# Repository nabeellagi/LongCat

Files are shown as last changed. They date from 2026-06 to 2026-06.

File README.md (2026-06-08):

<div align="center">

<!-- Zine -->
<a href="zine/zine.png">
  Long Cat & FoxCharge Zine
</a>

---

# Long Cat & FoxCharge

**A custom ESP32-C6 retro game console + fox-themed powerbank, built from scratch.**  
*By Nabeel — 18, Indonesia*

```
   /\_____/\
  /  o   o  \
 ( ==  ^  == )
```

</div>

---

## What Is This?

Long Cat is a handheld retro game console built around a custom ESP32-C6 PCB, put inside a 3D-printed enclosure featuring a long, stoopid cat on the back. It has a 1.3" OLED screen, 5 interface buttons, and a passive buzzer.

FoxCharge is its companion: a fox-themed powerbank with its own custom PCB, and a "Charging Social Battery" label on the back — totally relateable.

---

## Why Does This Exist?
The whole thing exists because I wanted a device where anyone could write their own retro-style game in firmware and actually play it on real hardware! A customizable silly looking project.

---

## How To Use It

### Coding & Flashing

This is the main loop. Open up Arduino IDE, write your game, and flash it to the console over USB-C.

1. Install [Arduino IDE](https://www.arduino.cc/en/software) and add ESP32 board support
2. Plug the console into your PC via USB-C
3. Open or write your game sketch
4. Select the correct board: **ESP32C6 Dev Module**
5. Hit upload, watch it flash, iterate :D

The enclosure pops open magnetically so you never need to unscrew anything to get to the board.

### Playing & Sharing

Once your game is ready and you want to take it somewhere — or just not be tethered to a laptop:

1. Plug the console into the **FoxCharge powerbank** via USB-C
2. The console powers up from the powerbank's 5V output
3. Hand it to a friend. Or play it yourself.

### Modifying the Hardware

Want to tweak the circuit? Change a pin assignment? Add something new? Here's where to go:

- **Console PCB** — open `PCB/board/board.kicad_pro` in [KiCad](https://www.kicad.org/). The schematic, layout, and production files are all in there.
- **FoxCharge PCB** — open `PCB/powerbank/powerbank.epro` in [EasyEDA](https://easyeda.com/). The Interactive BOM HTML (`PCB/powerbank/INTERACTIVE BOM/InteractiveBOM_PCB1_2026-5-30.html`) is very helpful for cross-referencing components on the board visually.

---

## Hardware Overview

### Console

The brain of Long Cat. Designed in KiCad, built around the ESP32-C6.

| Part | What it does |
|---|---|
| **ESP32-C6** | The microcontroller. RISC-V, Wi-Fi 6, BLE 5. Runs your game code. |
| **1.3" OLED** | The screen. I2C, connected on SDA/SCL. This is where everything gets drawn. |
| **5x Buttons** | `BTN_1` through `BTN_5` — your game inputs. Wired to dedicated GPIO pins. |
| **Passive Buzzer** | Makes noise. Driven by a transistor on `BUZZER_PIN`. Louder than what you'd expect!! |
| **Reset / Boot switches** | `SW1` = reset the board, `SW2` = enter bootloader. Useful during development. |
| **Debug header (J1)** | 6-pin header exposing EN, 3V3, TX, GND, RX, BOOT — for serial monitoring or alternate flashing setups. |

### FoxCharge Powerbank

The power source. Custom PCB designed in EasyEDA. Fox-themed. Sleeping fox on the front is load-bearing.

| Part | What it does |
|---|---|
| **Battery** | LiPo 103450 cell (~2000 mAh). |
| **Charge IC — TP4056** | Handles charging the LiPo safely from the USB-C input port. |
| **Boost IC — MT3608** | Steps up the battery voltage (~3.7V) to a stable 5V for the USB-C output. |
| **Protection IC — DW01A + FS8205A** | Protects the battery from overcharge, overdischarge, and short circuits. Keeps things from catching fire. |
| **USB-C Input** | Plug in a charger here to charge the battery. |
| **USB-C Output** | Plug the console here. This is what powers the game. |

---

## Assembly

### Long Cat Console

<p align="center">
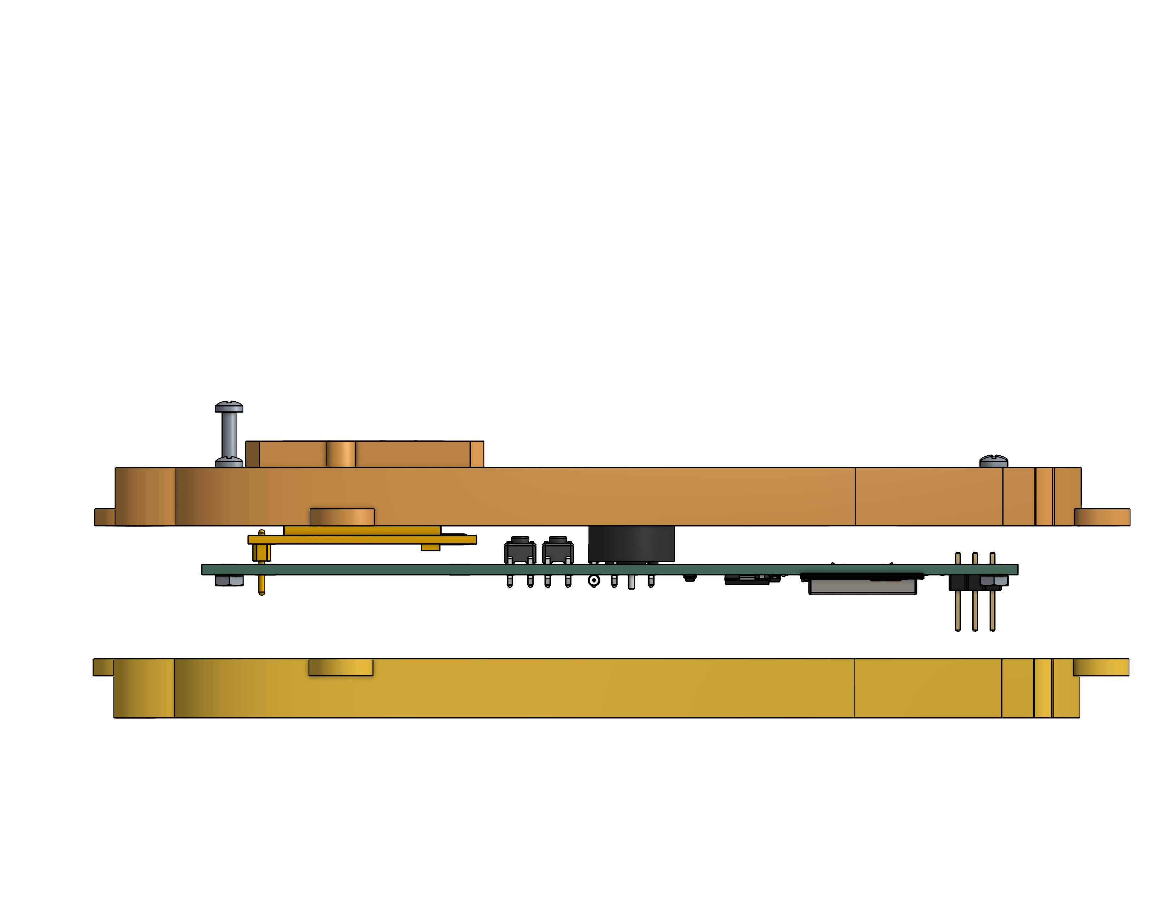
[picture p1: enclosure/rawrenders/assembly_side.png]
Console assembly side view
  
  <br/>
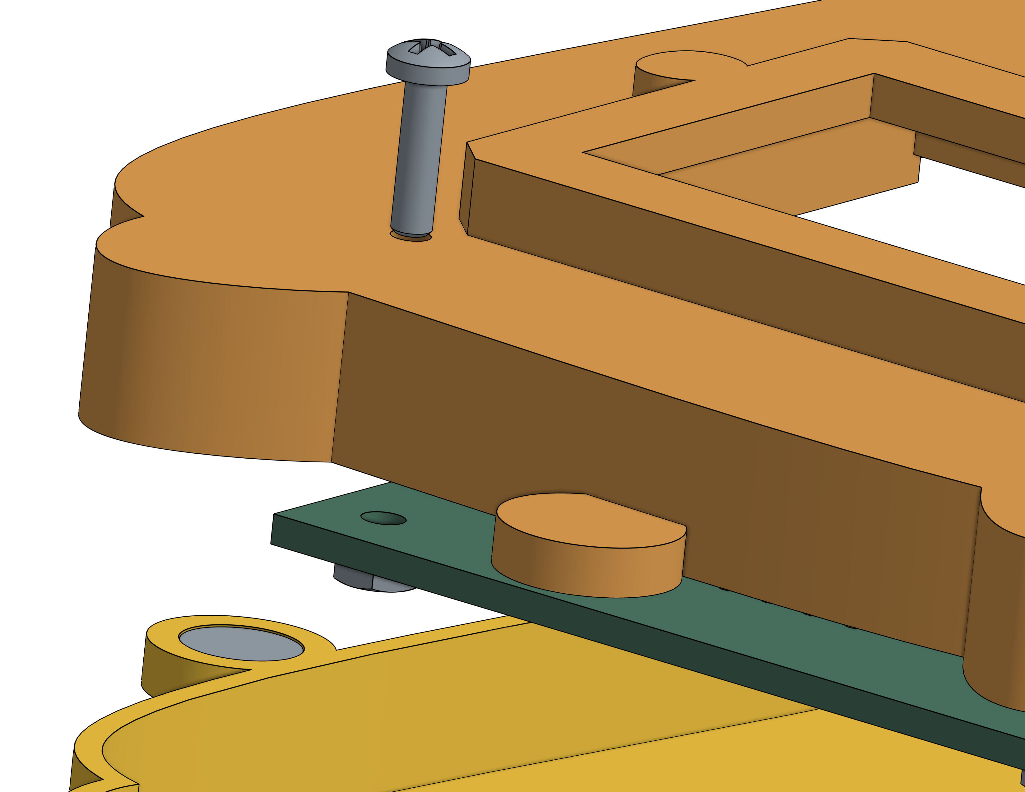
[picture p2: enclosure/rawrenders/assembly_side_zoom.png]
Console assembly side zoom
  
  <br/>
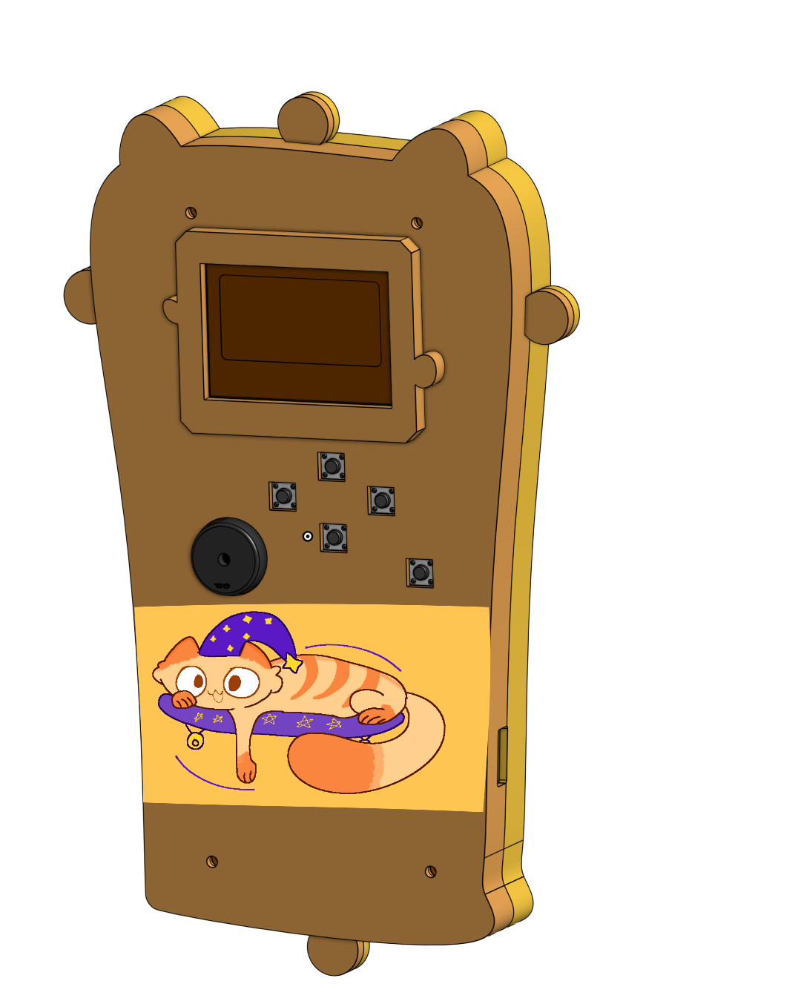
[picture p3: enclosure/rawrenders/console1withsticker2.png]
Console with Long Cat sticker
  
</p>

The front and back halves of the enclosure are held together using **6 x 2mm neodymium magnets** on the edges. This means the case snaps shut cleanly and can be pulled apart for flashing or debugging without any tools — which matters a lot when you're iterating on your game code.

To secure the PCB inside the front half: use **M2 screws with nylon M2 nuts**. Nylon nuts ensures the PCB will be locked into the top of the enclosure. Full screw spec is in the BOM (`REAL_BOM/console.csv`).

The Long Cat sticker goes on the back and the Sleepy cat on the front. **This is not optional!!!**.

---

### FoxCharge Powerbank

<p align="center">
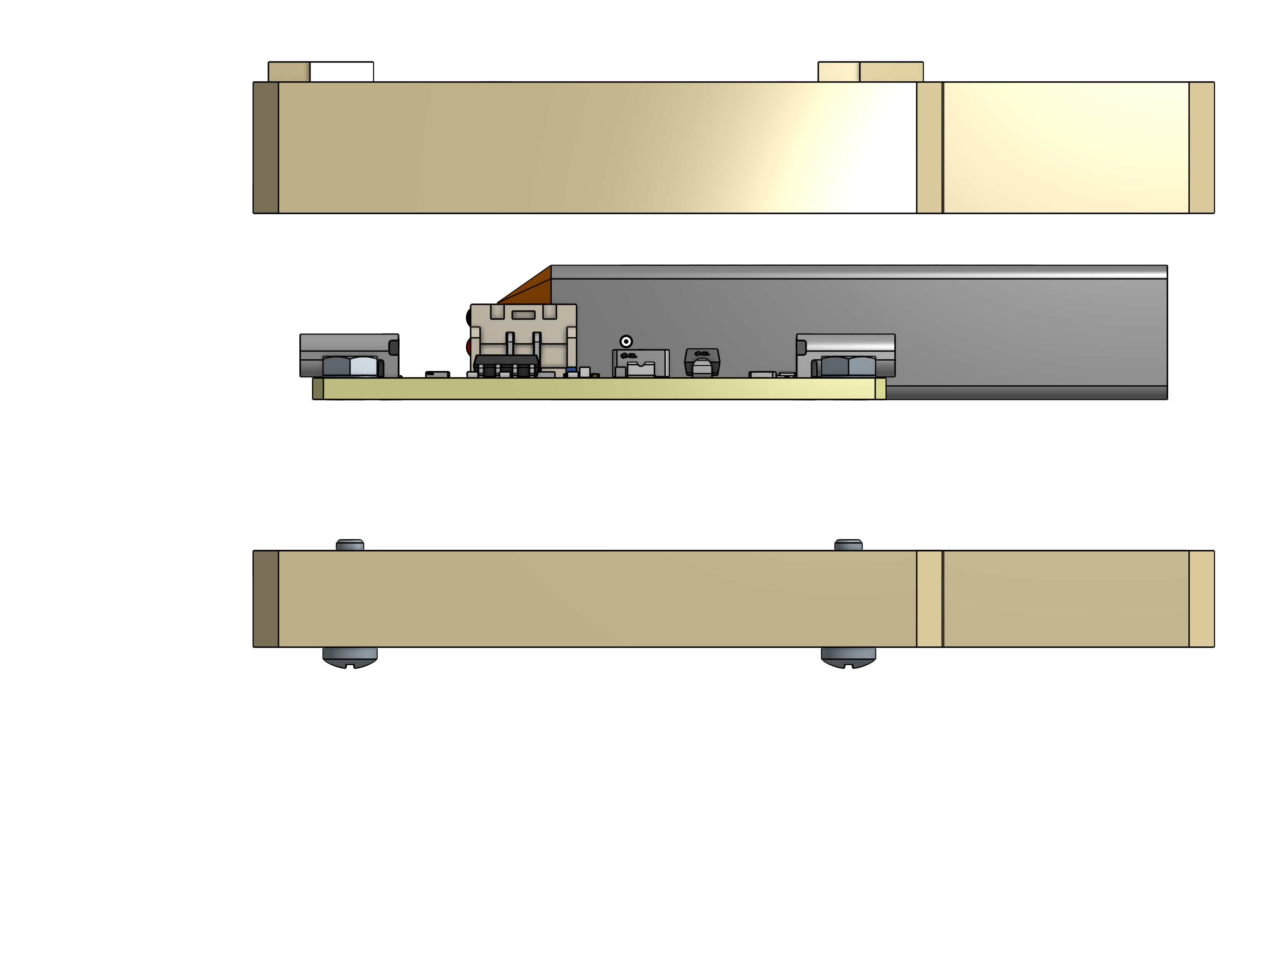
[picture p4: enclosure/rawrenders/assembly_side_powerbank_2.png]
Powerbank assembly view 2
  
  <br/>
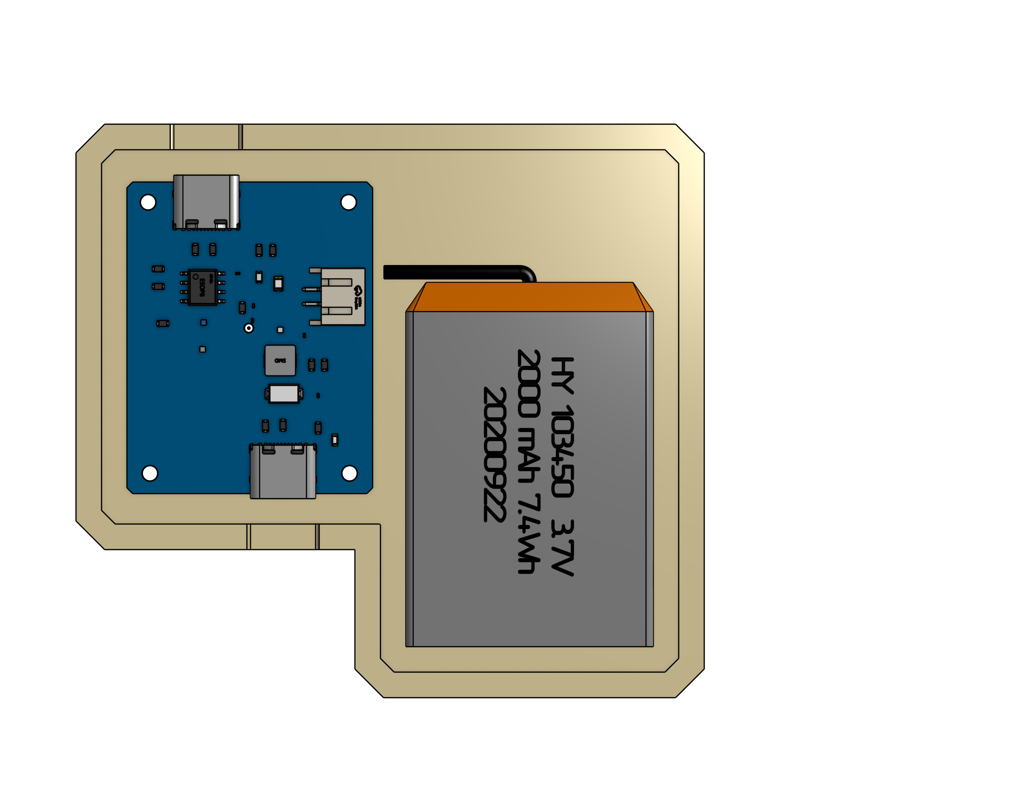
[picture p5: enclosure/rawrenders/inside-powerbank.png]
Powerbank inside view
  
  <br/>
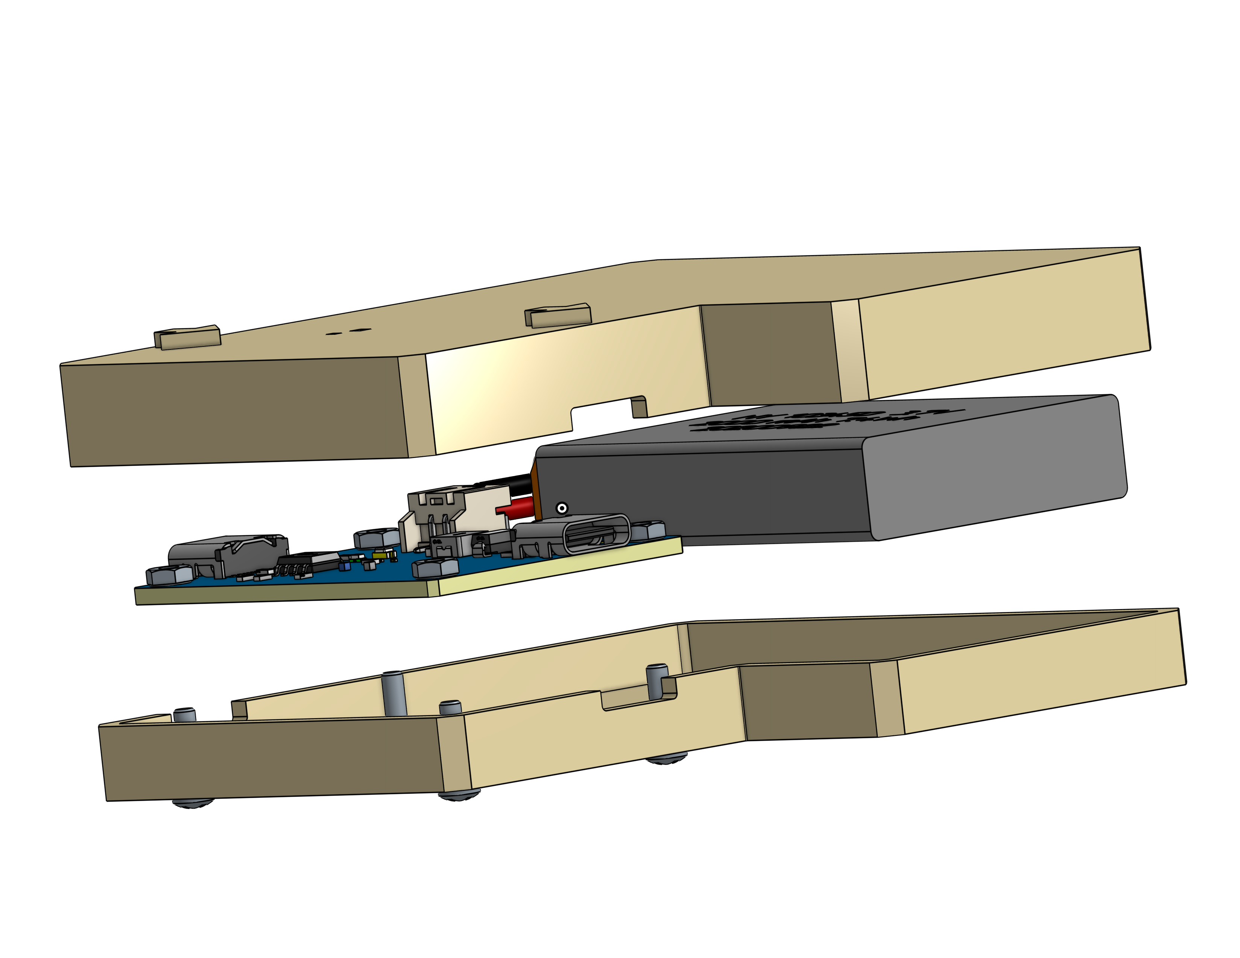
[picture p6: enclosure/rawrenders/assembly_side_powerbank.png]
Powerbank assembly side view
  
  <br/>
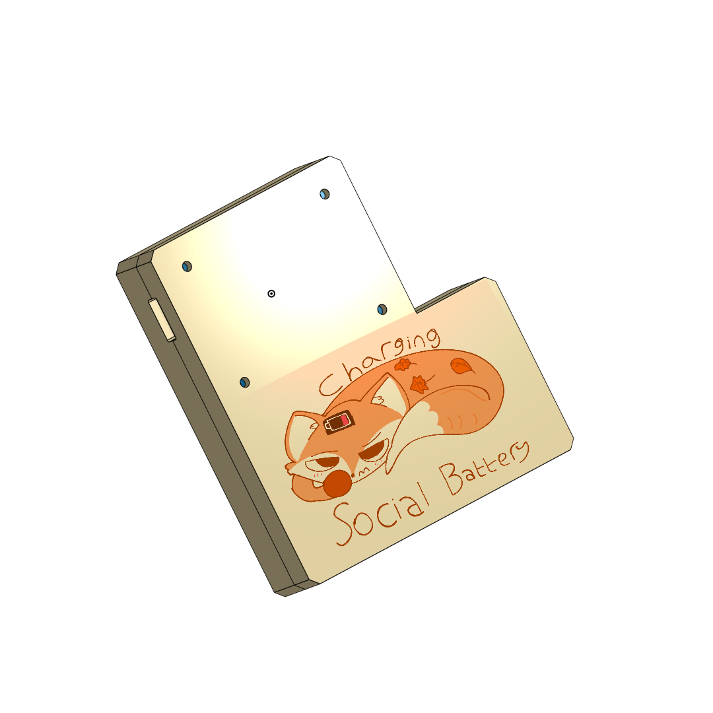
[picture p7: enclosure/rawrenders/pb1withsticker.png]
  
</p>

Inside the powerbank enclosure, the LiPo battery and PCB are separated using **padded EVA foam** to prevent contact, pressure damage, and general battery unhappiness.

On the inner edges, **Dual Lock Reclosable Fastener (24mm × 50cm Velcro-style)** is used to hold the assembly in place while still allowing it to be opened cleanly for battery replacement or inspection.
<p align="center">
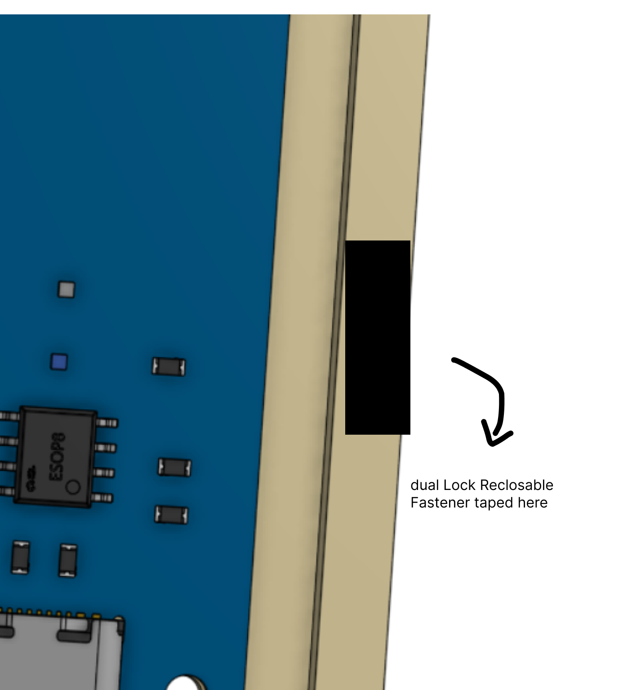
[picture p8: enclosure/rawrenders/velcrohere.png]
  
</p>
Same M2 screw + nylon nut approach as the console for securing the PCB. See `REAL_BOM/powerbank.csv` for the full list.

---

### PCB and Schematics Wiring

<p align="center">
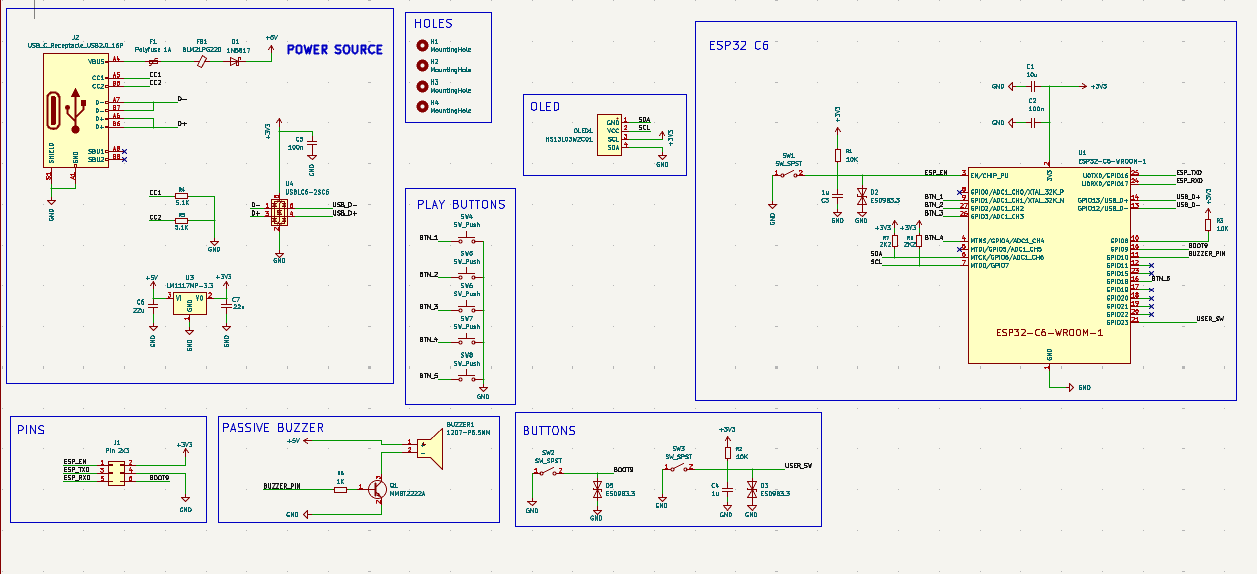
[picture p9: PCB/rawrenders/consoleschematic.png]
Console schematic
  
  <br/>
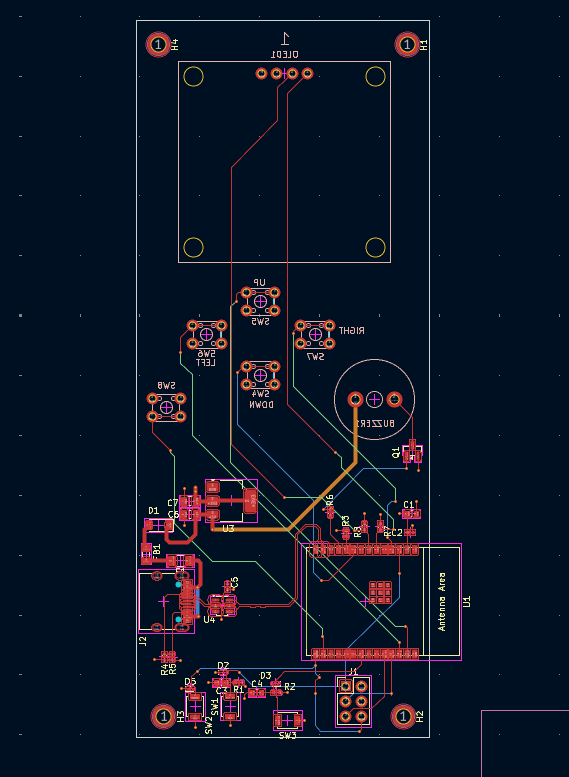
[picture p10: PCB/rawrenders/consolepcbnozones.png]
Console PCB without zones
  
  <br/>
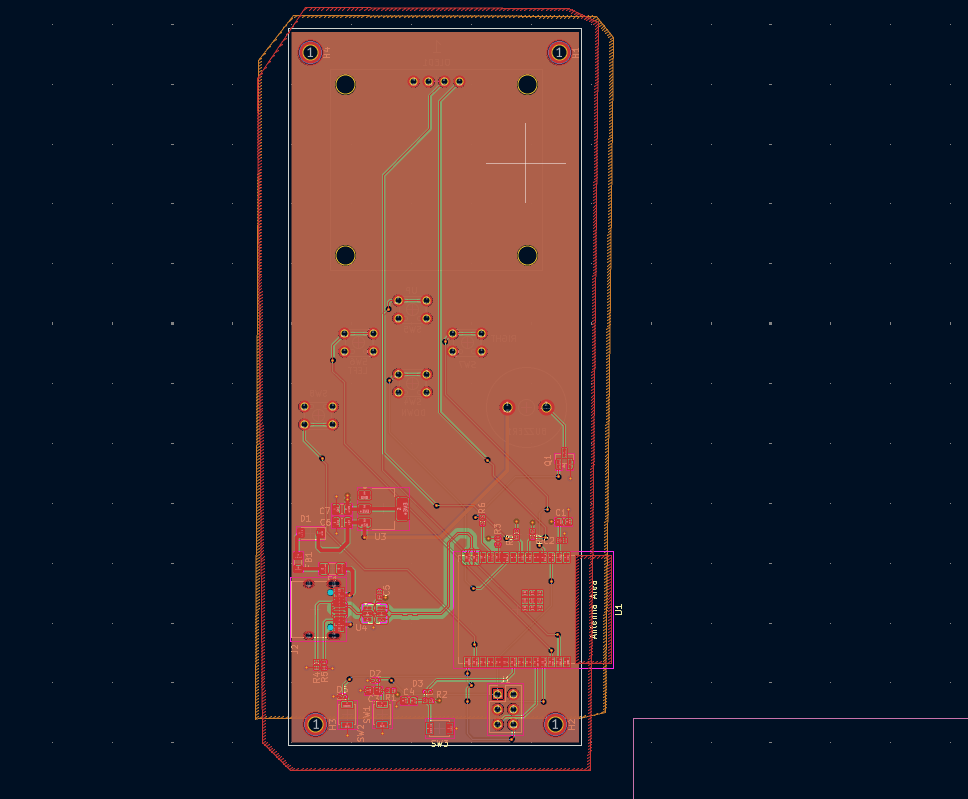
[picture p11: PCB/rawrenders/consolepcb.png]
Console PCB
  
  <br/>
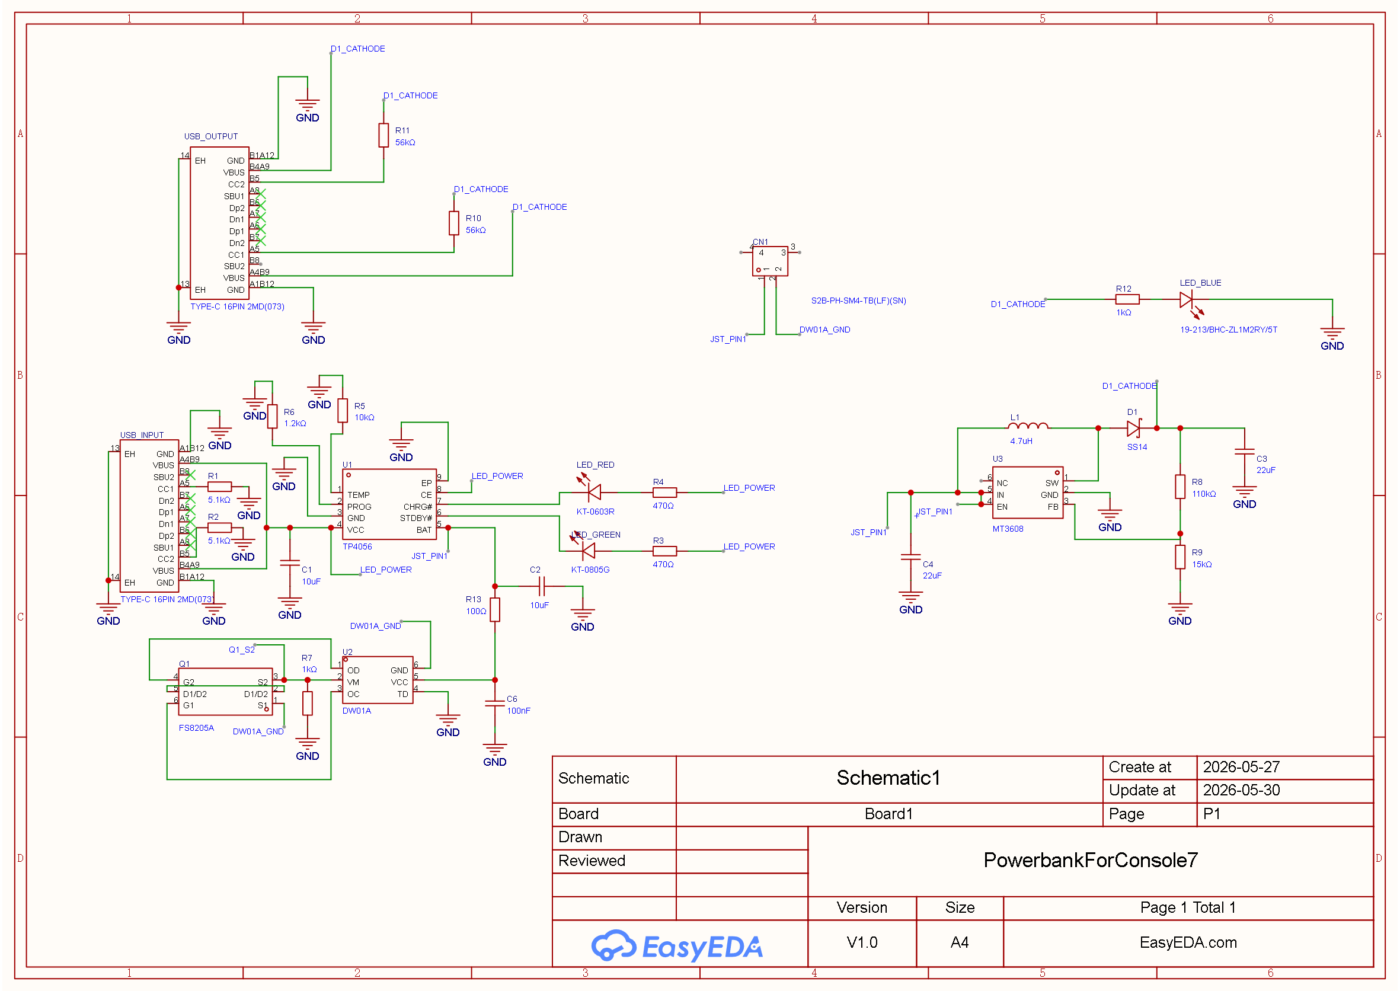
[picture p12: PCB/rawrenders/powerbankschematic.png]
Powerbank schematic
  
  <br/>
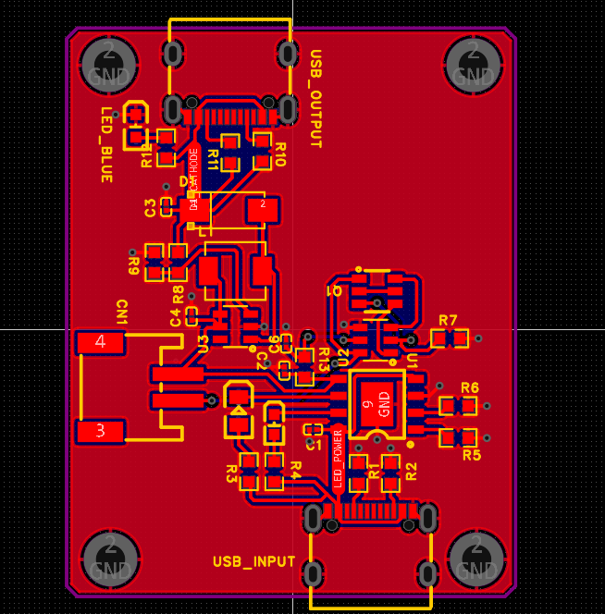
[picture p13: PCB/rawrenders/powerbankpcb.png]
Powerbank PCB
  

</p>

---

## Repository Structure

```
.
├── PCB/
│   ├── board/                          # Console PCB (KiCad)
│   │   ├── board.kicad_pcb
│   │   ├── board.kicad_sch
│   │   ├── board.kicad_pro
│   │   ├── STEP/board.step
│   │   └── production/
│   │       ├── board_gerber.zip        # Send this to your fab
│   │       ├── netlist.ipc
│   │       ├── bom.csv-JLCPCB BOM Tool.xls
│   │       └── raw_bom.csv
│   └── powerbank/                      # FoxCharge PCB (EasyEDA)
│       ├── powerbank.epro
│       ├── powerbank_netlist.tel
│       ├── STEP/
│       ├── GERBER/powerbank_gerber.zip
│       └── INTERACTIVE BOM/
│           ├── BOM_Board1_PCB1_2026-05-30.xlsx
│           └── InteractiveBOM_PCB1_2026-5-30.html
├── enclosure/
│   ├── rawrenders/                     # Reference renders for assembly + zine
│   ├── console/
│   │   ├── enclosure_only.3mf          # Print this
│   │   ├── fullassemblyvisual.3mf      # Full assembly reference
│   │   └── fullassemblyvisual.step
│   └── powerbank/
│       ├── enclosure_only.3mf
│       ├── fullassemblyvisual.3mf
│       └── fullassemblyvisual.step
├── firmware/                           # Hello World for the console
├── stickers/
│   ├── longcat.png
│   ├── sleepcat.png
│   └── tiredfox.png
├── REAL_BOM/
│   ├── all.xlsx
│   ├── console.csv
│   ├── powerbank.csv
│   └── total.csv
└── zine/                               # Full project zine, PDF + PNG versions
```

---

## Stickers

Three stickers are included in `stickers/`. Print them on sticker paper and apply accordingly.

- `longcat.png` — The long, stoopid cat. Goes on the back of the console.
- `sleepcat.png` — Sleeping cat. Goes on the front of the console.
- `tiredfox.png` — The FoxCharge mascot. Goes on the powerbank.

---

## Zine

The `zine/` folder contains both a PDF and PNG version of the project zine, made for Fallout 2026. It's the fastest way to understand what this project is about.

---

## Firmware

An example given inside firmware folder. A simple mechanism to see OLED's output based on button presses. Use it as a starting point for your own games!

---

## OnShape Links
- [Check out the console enclosure](https://cad.onshape.com/documents/60f1f5947965f7d5a461c6ea/w/f31938c96fb582cd81c805fc/e/fdd6c70c168f7e2d293480c5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)
- [Check out the powerbank enclosure](https://cad.onshape.com/documents/b2bd0c68b06dcbd9cb3796b5/w/1a262ecd5f3c2cdca41969fa/e/07a6aa8a28141834d2369848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)

## Bill of Materials

Full BOM is split by subsystem for easier ordering, here are the BOM links:

| File | Contents |
|---|---|
| [`REAL_BOM/console.csv`](https://github.com/nabeellagi/LongCat/blob/main/REAL_BOM/console.csv) | All console PCB components |
| [`REAL_BOM/powerbank.csv`](https://github.com/nabeellagi/LongCat/blob/main/REAL_BOM/powerbank.csv) | All powerbank PCB components |
| [`REAL_BOM/all.xlsx`](https://github.com/nabeellagi/LongCat/blob/main/REAL_BOM/all.xlsx) | Combined, formatted |
| [`REAL_BOM/total.csv`](https://github.com/nabeellagi/LongCat/blob/main/REAL_BOM/total.csv) | Grand total cost summary |

Additional BOM:

1. `PCB/board/production/bom.csv-JLCPCB BOM Tool.xls` is JLCPCB-formatted, ready to upload
2. For the powerbank PCB, the Interactive BOM HTML (`PCB/powerbank/INTERACTIVE BOM/InteractiveBOM_PCB1_2026-5-30.html`) is the friendliest way to cross-reference components with their board placement.

---

### Console BOM

| # | Item | Description | Qty | Unit ($) | Total ($) | Running Total ($) | Link |
|---|---|---|---|---|---|---|---|
| 1 | ESPRESSIF ESP32-C6-WROOM-1-N8 | ESP32 Chip | 1 | 4.3546 | 4.3546 | 4.3546 | [LCSC](https://www.lcsc.com/product-detail/C5366877.html) |
| 2 | TECH PUBLIC TPESD9B3.3ST5G | Diode | 3 | 0.0396 | 0.1188 | 4.4734 | [LCSC](https://www.lcsc.com/product-detail/C2682285.html) |
| 3 | TECH PUBLIC USBLC6-2SC6 | Transient Voltage Suppressor | 1 | 0.0410 | 0.0410 | 4.5144 | [LCSC](https://www.lcsc.com/product-detail/C2827654.html) |
| 4 | BZCN TSC016A04518A | Tactile Switches (console buttons) | 5 | 0.0107 | 0.0535 | 4.5679 | [LCSC](https://www.lcsc.com/product-detail/C2888493.html) |
| 5 | TI LM1117MP-3.3 | Voltage Regulator | 1 | 0.2975 | 0.2975 | 4.8654 | [LCSC](https://www.lcsc.com/product-detail/C3750685.html) |
| 6 | XHXDZ 1207-P6.5MM | Buzzer | 1 | 0.0316 | 0.0316 | 4.8970 | [LCSC](https://www.lcsc.com/product-detail/C49246964.html) |
| 7 | 1N5817W | Diode Schottky | 1 | 0.0197 | 0.0197 | 4.9167 | [LCSC](https://www.lcsc.com/product-detail/C727113.html) |
| 8 | MMBT2222A | Bipolar Transistor | 1 | 0.0155 | 0.0155 | 4.9322 | [LCSC](https://www.lcsc.com/product-detail/C7420351.html) |
| 9 | HS HS13L03W2C01 | 1.3" OLED | 1 | 5.3558 | 5.3558 | 10.2880 | [LCSC](https://www.lcsc.com/product-detail/C7465997.html) |
| 10 | muRata BLM21PG220SN1D | Ferrite Bead | 1 | 0.0308 | 0.0308 | 10.3188 | [LCSC](https://www.lcsc.com/product-detail/C88993.html) |
| 11 | Resistor 1kΩ | R6 | 1 | 0.0011 | 0.0011 | 10.3199 | [LCSC](https://www.lcsc.com/product-detail/C11702.html) |
| 12 | Capacitor 100nF | C2, C5 | 2 | 0.0016 | 0.0032 | 10.3231 | [LCSC](https://www.lcsc.com/product-detail/C1525.html) |
| 13 | Capacitor 1uF | C3, C4 | 2 | 0.0098 | 0.0196 | 10.3427 | [LCSC](https://www.lcsc.com/product-detail/C15849.html) |
| 14 | Korean Hroparts Elec TYPE-C-31-M-12 | USB-C Input | 1 | 0.1725 | 0.1725 | 10.5152 | [LCSC](https://www.lcsc.com/product-detail/C165948.html) |
| 15 | Capacitor 10uF | C1 | 1 | 0.2500 | 0.2500 | 10.7652 | [LCSC](https://www.lcsc.com/product-detail/C19702.html) |
| 16 | B3U-1000P | ESP32 Buttons | 3 | 0.1781 | 0.5343 | 11.2995 | [LCSC](https://www.lcsc.com/product-detail/C231329.html) |
| 17 | Resistor 2.2kΩ | R7, R8 | 2 | 0.0008 | 0.0008 | 11.3003 | [LCSC](https://www.lcsc.com/product-detail/C25879.html) |
| 18 | Resistor 5.1kΩ | R4, R5 | 2 | 0.0009 | 0.0018 | 11.3021 | [LCSC](https://www.lcsc.com/product-detail/C25905.html) |
| 19 | Capacitor 22uF | C6, C7 | 2 | 0.0618 | 0.1236 | 11.4257 | [LCSC](https://www.lcsc.com/product-detail/C45783.html) |
| 20 | R+O SMD1206-050-30 | Reset Fuse | 1 | 0.0599 | 0.0599 | 11.4856 | [LCSC](https://www.lcsc.com/product-detail/C46641016.html) |
| 21 | ZHOURI 2.54-2*3 | Pin Header | 1 | 0.0562 | 0.0562 | 11.5418 | [LCSC](https://www.lcsc.com/product-detail/C5116479.html) |
| 22 | Resistor 10kΩ | R1, R2, R3 | 3 | 0.0009 | 0.0027 | 11.5445 | [LCSC](https://www.lcsc.com/product-detail/C60490.html) |
| 23 | 6×2mm Strong Magnet Neodymium | Enclosure attach/detach | 6 | 0.0530 | 0.3180 | 11.8625 | [Tokopedia](https://tk.tokopedia.com/ZSxcDM12f/) |
| 24 | M2×8 Screw | Screw PCB to enclosure | 4 | 0.0500 | 0.2000 | 12.0625 | [Tokopedia](https://tk.tokopedia.com/ZSxcDKrx9/) |
| 25 | M2 Nylon Nut | Lock the screw | 4 | 0.0540 | 0.2160 | 12.2785 | [Tokopedia](https://tk.tokopedia.com/ZSxcP4PVw/) |
| 26 | Engineering Fee | Engineering Fee | 1 | 24.0000 | 24.0000 | 36.2785 | [JLCPCB](https://jlcpcb.com/) |
| 27 | PCB Board | PCB Board | 1 | 1.6000 | 1.6000 | 37.8785 | [JLCPCB](https://jlcpcb.com/) |
| 28 | PCBA Price | If enabled PCBA option | 1 | 42.1700 | 42.1700 | 80.0485 | [JLCPCB](https://jlcpcb.com/) |

> **Console subtotal (without PCBA): $37.88** — components + engineering fee + PCB board  
> **Console subtotal (with PCBA): $80.05** — includes assembly service

---

### FoxCharge Powerbank BOM

| # | Item | Description | Qty | Unit ($) | Total ($) | Running Total ($) | Link |
|---|---|---|---|---|---|---|---|
| 1 | TPOWER TP4056 | Charging Module | 1 | 0.1194 | 0.1194 | 0.1194 | [LCSC](https://www.lcsc.com/product-detail/C382139.html) |
| 2 | PUOLOP DW01A | Battery Protection (overcharge prevention) | 1 | 0.0428 | 0.0428 | 0.1622 | [LCSC](https://www.lcsc.com/product-detail/C351410.html) |
| 3 | XI'AN Aerosemi Tech MT3608 | Boost Step-Up Regulator | 1 | 0.0786 | 0.0786 | 0.2408 | [LCSC](https://www.lcsc.com/product-detail/C84817.html) |
| 4 | TECH PUBLIC FS8205A | LiPo Battery Protection FET | 1 | 0.0575 | 0.0575 | 0.2983 | [LCSC](https://www.lcsc.com/product-detail/C2830320.html) |
| 5 | SHOU HAN TYPE-C 16PIN 2MD(073) | USB-C Input and Output | 2 | 0.0742 | 0.1484 | 0.4467 | [LCSC](https://www.lcsc.com/product-detail/C2765186.html) |
| 6 | Hubei KENTO Elec KT-0603R | Red LED | 1 | 0.0070 | 0.0070 | 0.4537 | [LCSC](https://www.lcsc.com/product-detail/C2286.html) |
| 7 | Hubei KENTO Elec KT-0805G | Green LED | 1 | 0.0163 | 0.0163 | 0.4700 | [LCSC](https://www.lcsc.com/product-detail/C2297.html) |
| 8 | EVERLIGHT 19-213/BHC-ZL1M2RY/5T | Blue LED | 1 | 0.0381 | 0.0381 | 0.5081 | [LCSC](https://www.lcsc.com/product-detail/C2987539.html) |
| 9 | cjiang FXL0420-4R7-M | Inductor 4.7µH | 1 | 0.2076 | 0.2076 | 0.7157 | [LCSC](https://www.lcsc.com/product-detail/C167208.html) |
| 10 | JST S2B-PH-SM4-TB(LF)(SN) | JST Pin for Battery | 1 | 0.2040 | 0.2040 | 0.9197 | [LCSC](https://www.lcsc.com/product-detail/C295747.html) |
| 11 | LiPo 104050 2000mAh 3.7V | Battery | 1 | 4.8300 | 4.8300 | 5.7497 | [Tokopedia](https://tk.tokopedia.com/ZSxtYCQTL/) |
| 12 | Resistor 5.1kΩ | R1, R2 | 2 | 0.0003 | 0.0006 | 5.7503 | [LCSC](https://www.lcsc.com/product-detail/C23186.html) |
| 13 | Resistor 470Ω | R3, R4 | 2 | 0.0003 | 0.0006 | 5.7509 | [LCSC](https://www.lcsc.com/product-detail/C23179.html) |
| 14 | Resistor 10kΩ | R5 | 1 | 0.0003 | 0.0003 | 5.7512 | [LCSC](https://www.lcsc.com/product-detail/C25804.html) |
| 15 | Resistor 1.2kΩ | R6 | 1 | 0.0003 | 0.0003 | 5.7515 | [LCSC](https://www.lcsc.com/product-detail/C114605.html) |
| 16 | Resistor 1kΩ | R7, R12 | 2 | 0.0003 | 0.0006 | 5.7521 | [LCSC](https://www.lcsc.com/product-detail/C22548.html) |
| 17 | Resistor 110kΩ | R8 | 1 | 0.0002 | 0.0002 | 5.7523 | [LCSC](https://www.lcsc.com/product-detail/C25805.html) |
| 18 | Resistor 15kΩ | R9 | 1 | 0.0003 | 0.0003 | 5.7526 | [LCSC](https://www.lcsc.com/product-detail/C114661.html) |
| 19 | Resistor 56kΩ | R10, R11 | 2 | 0.0003 | 0.0006 | 5.7532 | [LCSC](https://www.lcsc.com/product-detail/C23206.html) |
| 20 | Resistor 100Ω | R13 | 1 | 0.0003 | 0.0003 | 5.7535 | [LCSC](https://www.lcsc.com/product-detail/C105588.html) |
| 21 | Capacitor 10uF | C1, C2 | 2 | 0.0019 | 0.0038 | 5.7573 | [LCSC](https://www.lcsc.com/product-detail/C19702.html) |
| 22 | Capacitor 22uF | C3, C4 | 2 | 0.0027 | 0.0054 | 5.7627 | [LCSC](https://www.lcsc.com/product-detail/C86295.html) |
| 23 | Capacitor 100nF | C6 | 1 | 0.0003 | 0.0003 | 5.7630 | [LCSC](https://www.lcsc.com/product-detail/C160831.html) |
| 24 | 3M Dual Lock Fastener 24mm×50cm | Enclosure attach/detach (use 3mm×3mm pieces) | 6 | 0.0010 | 0.0060 | 5.7690 | [Tokopedia](https://tk.tokopedia.com/ZSxcDnUcT/) |
| 25 | M2×8 Screw | Screw PCB to enclosure | 4 | 0.0500 | 0.2000 | 5.9690 | [Tokopedia](https://tk.tokopedia.com/ZSxcDKrx9/) |
| 26 | M2 Nylon Nut | Lock the screw | 4 | 0.0540 | 0.2160 | 6.1850 | [Tokopedia](https://tk.tokopedia.com/ZSxc5xuDv/) |
| 27 | PCB Board | PCB Board | 1 | 1.0000 | 1.0000 | 7.1850 | [JLCPCB](https://jlcpcb.com/) |
| 28 | PCBA Price | If enabled PCBA option | 1 | 70.2500 | 70.2500 | 77.4350 | [JLCPCB](https://jlcpcb.com/) |

> **Powerbank subtotal (without PCBA): $7.19** — components + PCB board  
> **Powerbank subtotal (with PCBA): $77.44** — includes assembly service

---

### Grand Total

| Scenario | Console | Powerbank | **Total** |
|---|---|---|---|
| **Without PCBA** (self-solder) | $37.88 | $7.19 | **$45.06** |
| **With PCBA** (JLCPCB assembles) | $80.05 | $77.44 | **$157.48** |

> PCBA (PCB Assembly) is the option where JLCPCB solders all SMD components onto the board for you.

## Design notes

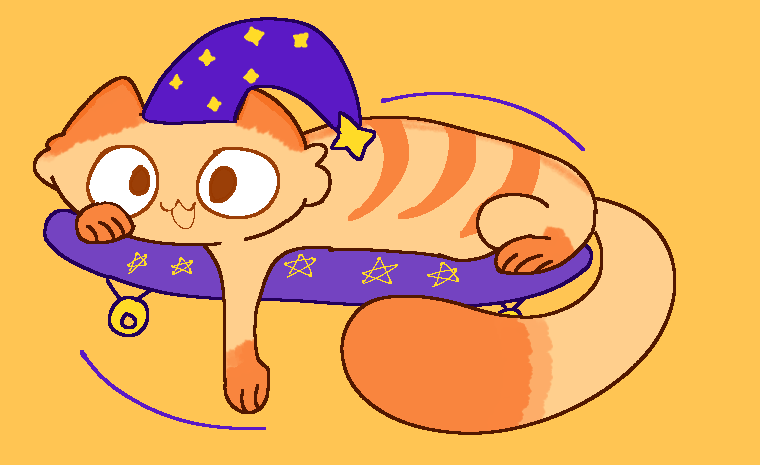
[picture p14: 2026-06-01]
stickers/sleepcat.png

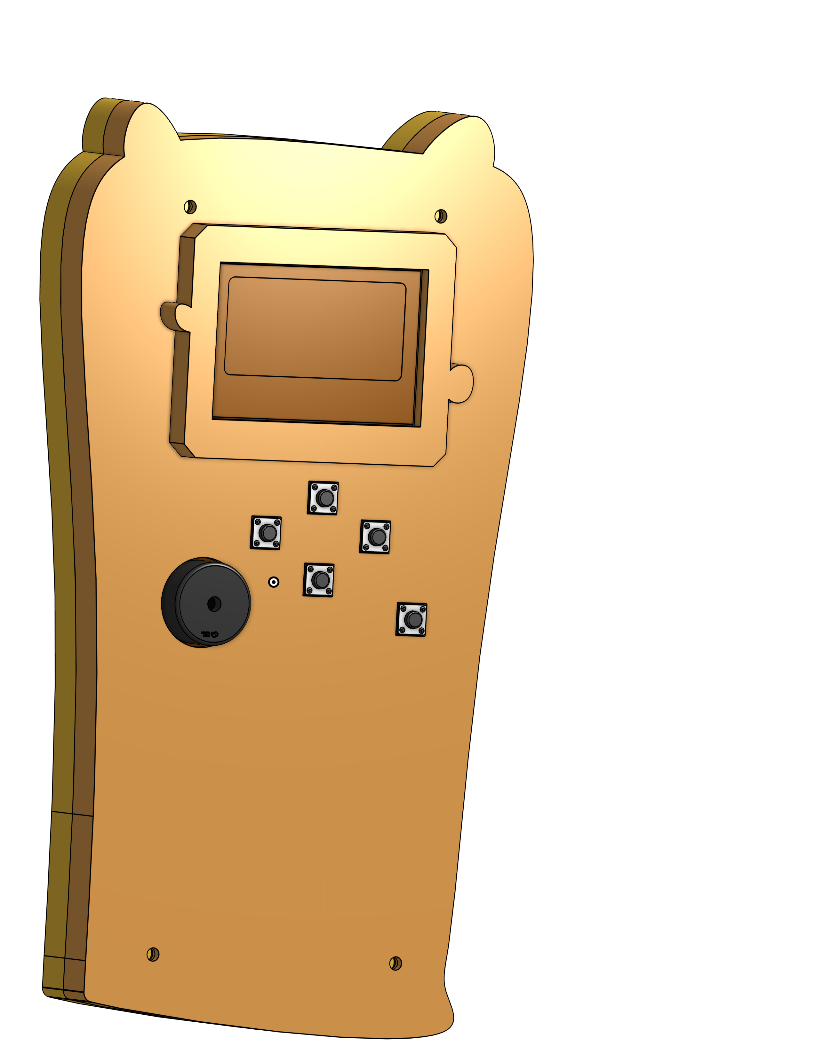
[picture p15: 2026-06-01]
enclosure/rawrenders/console1.png

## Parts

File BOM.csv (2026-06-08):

Number | Item | Description | Quantity | Unit Price ($) | Total Price ($) | URL | Source | Running Total ($ with Tax)
1 | ESPRESSIF ESP32-C6-WROOM-1-N8 | ESP32 Chip | 1 | 4.3546 | 4.3546 | https://www.lcsc.com/product-detail/C5366877.html | Console | 4.3546
2 | TECH PUBLIC TPESD9B3.3ST5G | Diode | 3 | 0.0396 | 0.1188 | https://www.lcsc.com/product-detail/C2682285.html | Console | 4.4734
3 | TECH PUBLIC USBLC6-2SC6 | Transient Voltage Supressor | 1 | 0.041 | 0.041 | https://www.lcsc.com/product-detail/C2827654.html | Console | 4.5144
4 | BZCN TSC016A04518A | Tactile Switches for console button | 5 | 0.0107 | 0.0535 | https://www.lcsc.com/product-detail/C2888493.html | Console | 4.5679
5 | TI LM1117MP-3.3 | Voltage Regulators | 1 | 0.2975 | 0.2975 | https://www.lcsc.com/product-detail/C3750685.html | Console | 4.8654
6 | XHXDZ 1207-P6.5MM | Buzzer | 1 | 0.0316 | 0.0316 | https://www.lcsc.com/product-detail/C49246964.html | Console | 4.897
7 | 1N5817W | DIODE SCHOTTKY | 1 | 0.0197 | 0.0197 | https://www.lcsc.com/product-detail/C727113.html | Console | 4.9167
8 | MMBT2222A | Bipolar Transistor | 1 | 0.0155 | 0.0155 | https://www.lcsc.com/product-detail/C7420351.html | Console | 4.9322
9 | HS HS13L03W2C01 | 1.3" OLED | 1 | 5.3558 | 5.3558 | https://www.lcsc.com/product-detail/C7465997.html | Console | 10.288
10 | muRata BLM21PG220SN1D | Ferrite Beads and Chips | 1 | 0.0308 | 0.0308 | https://www.lcsc.com/product-detail/C88993.html | Console | 10.3188
11 | Resistor 1kΩ | R6 | 1 | 0.0011 | 0.0011 | https://www.lcsc.com/product-detail/C11702.html | Console | 10.3199
12 | Capacitor 100nF | C2, C5 | 2 | 0.0016 | 0.0032 | https://www.lcsc.com/product-detail/C1525.html | Console | 10.3231
13 | Capacitor 1uF | C3, C4 | 2 | 0.0098 | 0.0196 | https://www.lcsc.com/product-detail/C15849.html | Console | 10.3427
14 | Korean Hroparts Elec TYPE-C-31-M-12 | USB C Input | 1 | 0.1725 | 0.1725 | https://www.lcsc.com/product-detail/C165948.html | Console | 10.5152
15 | Capacitor 10uF | C1 | 1 | 0.25 | 0.25 | https://www.lcsc.com/product-detail/C19702.html | Console | 10.7652
16 | B3U-1000P | ESP32 buttons | 3 | 0.1781 | 0.5343 | https://www.lcsc.com/product-detail/C231329.html | Console | 11.2995
17 | Resistor 2.2kΩ | R7, R8 | 2 | 0.0008 | 0.0008 | https://www.lcsc.com/product-detail/C25879.html | Console | 11.3003
18 | Resistor 5.1kΩ | R4, R5 | 2 | 0.0009 | 0.0018 | https://www.lcsc.com/product-detail/C25905.html | Console | 11.3021
19 | Capacitor 22uF | C6, C7 | 2 | 0.0618 | 0.1236 | https://www.lcsc.com/product-detail/C45783.html | Console | 11.4257
20 | R+O SMD1206-050-30 | Reset Fuse | 1 | 0.0599 | 0.0599 | https://www.lcsc.com/product-detail/C46641016.html | Console | 11.4856
21 | ZHOURI 2.54-2*3 | Pin Header | 1 | 0.0562 | 0.0562 | https://www.lcsc.com/product-detail/C5116479.html | Console | 11.5418
22 | Resistor 10kΩ | R1,R2,R3 | 3 | 0.0009 | 0.0027 | https://www.lcsc.com/product-detail/C60490.html | Console | 11.5445
23 | 6x2mm Strong Magnet Neodymium | To make the enclosure easy to attach-dettach | 6 | 0.053 | 0.318 | https://tk.tokopedia.com/ZSxcDM12f/ | Console | 11.8625
24 | M2X8 Screw | Screw PCB to enclosure | 4 | 0.05 | 0.2 | https://tk.tokopedia.com/ZSxcDKrx9/ | Console | 12.0625
25 | M2 Nylon Nut | Locking the screw | 4 | 0.054 | 0.216 | https://tk.tokopedia.com/ZSxcP4PVw/ | Console | 12.2785
26 | Engineering Fee | Engineering Fee | 1 | 24.0 | 24.0 | https://jlcpcb.com/ | Console | 36.2785
27 | PCB Board | PCB Board | 1 | 1.6 | 1.6 | https://jlcpcb.com/ | Console | 37.8785
28 | PCBA Price | If enabled PCBA option | 1 | 42.17 | 42.17 | https://jlcpcb.com/ | Console | 80.0485
29 | TPOWER TP4056 | Charging Module | 1 | 0.1194 | 0.1194 | https://www.lcsc.com/product-detail/C382139.html?globalKeyword=C382139&s_z=n_q_C382139 | Powerbank | 80.1679
30 | PUOLOP DW01A | Battery protection, prevents overcharging | 1 | 0.0428 | 0.0428 | https://www.lcsc.com/product-detail/C351410.html?globalKeyword=C351410&s_z=n_q_C351410 | Powerbank | 80.2107
31 | XI'AN Aerosemi Tech MT3608 | Boost Step-Up Regulator | 1 | 0.0786 | 0.0786 | https://www.lcsc.com/product-detail/C84817.html?globalKeyword=C84817&s_z=n_q_C84817 | Powerbank | 80.2893
32 | TECH PUBLIC FS8205A | LiPo Battery Protection | 1 | 0.0575 | 0.0575 | https://www.lcsc.com/product-detail/C2830320.html?globalKeyword=C2830320&s_z=n_q_C2830320 | Powerbank | 80.3468
33 | SHOU HAN TYPE-C 16PIN 2MD(073) | USB C Input and Output | 2 | 0.0742 | 0.1484 | https://www.lcsc.com/product-detail/C2765186.html?globalKeyword=C2765186&s_z=n_q_C2765186 | Powerbank | 80.4952
34 | Hubei KENTO Elec KT-0603R | Red Led | 1 | 0.007 | 0.007 | https://www.lcsc.com/product-detail/C2286.html?globalKeyword=C2286&s_z=n_q_C2286 | Powerbank | 80.5022
35 | Hubei KENTO Elec KT-0805G | Green Led | 1 | 0.0163 | 0.0163 | https://www.lcsc.com/product-detail/C2297.html?globalKeyword=C2297&s_z=n_q_C2297 | Powerbank | 80.5185
36 | EVERLIGHT 19-213/BHC-ZL1M2RY/5T | Blue Led | 1 | 0.0381 | 0.0381 | https://www.lcsc.com/product-detail/C2987539.html?globalKeyword=C2987539&s_z=n_q_C2987539 | Powerbank | 80.5566
37 | cjiang FXL0420-4R7-M | Inductor | 1 | 0.2076 | 0.2076 | https://www.lcsc.com/product-detail/C167208.html?globalKeyword=C167208&s_z=n_q_C167208 | Powerbank | 80.7642
38 | JST S2B-PH-SM4-TB(LF)(SN) | JST Pin for Battery | 1 | 0.204 | 0.204 | https://www.lcsc.com/product-detail/C295747.html?globalKeyword=C295747&s_z=n_q_C295747 | Powerbank | 80.9682
39 | LiPo 104050 2000mAh 3.7V | Battery | 1 | 4.83 | 4.83 | https://tk.tokopedia.com/ZSxtYCQTL/ | Powerbank | 85.7982
40 | Resistor 5.1kΩ | R1,R2 | 2 | 0.0003 | 0.0006 | https://www.lcsc.com/product-detail/C23186.html | Powerbank | 85.7988
41 | Resistor 470Ω | R3,R4 | 2 | 0.0003 | 0.0006 | https://www.lcsc.com/product-detail/C23179.html | Powerbank | 85.7994
42 | Resistor 10kΩ | R5 | 1 | 0.0003 | 0.0003 | https://www.lcsc.com/product-detail/C25804.html | Powerbank | 85.7997
43 | Resistor 1.2kΩ | R6 | 1 | 0.0003 | 0.0003 | https://www.lcsc.com/product-detail/C114605.html | Powerbank | 85.8
44 | Resistor 1kΩ | R7,R12 | 2 | 0.0003 | 0.0006 | https://www.lcsc.com/product-detail/C22548.html | Powerbank | 85.8006
45 | Resistor 110kΩ | R8 | 1 | 0.0002 | 0.0002 | https://www.lcsc.com/product-detail/C25805.html | Powerbank | 85.8008
46 | Resistor 15kΩ | R9 | 1 | 0.0003 | 0.0003 | https://www.lcsc.com/product-detail/C114661.html | Powerbank | 85.8011
47 | Resistor 56kΩ | R10,R11 | 2 | 0.0003 | 0.0006 | https://www.lcsc.com/product-detail/C23206.html | Powerbank | 85.8017
48 | Resistor 100Ω | R13 | 1 | 0.0003 | 0.0003 | https://www.lcsc.com/product-detail/C105588.html | Powerbank | 85.802
49 | Capacitor 10uF | C1,C2 | 2 | 0.0019 | 0.0038 | https://www.lcsc.com/product-detail/C19702.html | Powerbank | 85.8058
50 | Capacitor 22uF | C3,C4 | 2 | 0.0027 | 0.0054 | https://www.lcsc.com/product-detail/C86295.html | Powerbank | 85.8112
51 | Capacitor 100nF | C6 | 1 | 0.0003 | 0.0003 | https://www.lcsc.com/product-detail/C160831.html | Powerbank | 85.8115
52 | 3M Dual Lock Reclosable Fastener 24mm x 50cm Velcro acc (Usage 3mm x 3mm) | To make powerbank easy to attach-dettach | 6 | 0.001 | 0.006 | https://tk.tokopedia.com/ZSxcDnUcT/ | Powerbank | 85.8175
53 | M2X8 Screw | Screw PCB to enclosure | 4 | 0.05 | 0.2 | https://tk.tokopedia.com/ZSxcDKrx9/ | Powerbank | 86.0175
54 | M2 Nylon Nut | Locking the screw | 4 | 0.054 | 0.216 | https://tk.tokopedia.com/ZSxc5xuDv/ | Powerbank | 86.2335
55 | PCB Board | PCB Board | 1 | 1.0 | 1.0 | https://jlcpcb.com/ | Powerbank | 87.2335
56 | PCBA Price | If enabled PCBA option | 1 | 70.25 | 70.25 | https://jlcpcb.com/ | Powerbank | 157.4835

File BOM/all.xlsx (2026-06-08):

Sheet: CONSOLE
Number | Item | Description | Quantity | Unit Price ($) | Total Price ($) | URL | Running Total ($ with Tax)
1 | ESPRESSIF ESP32-C6-WROOM-1-N8 | ESP32 Chip | 1 | 4.3546 | 4.3546 | https://www.lcsc.com/product-detail/C5366877.html | 4.3546
2 | TECH PUBLIC TPESD9B3.3ST5G | Diode | 3 | 0.0396 | 0.1188 | https://www.lcsc.com/product-detail/C2682285.html | 4.4734
3 | TECH PUBLIC USBLC6-2SC6 | Transient Voltage Supressor | 1 | 0.041 | 0.041 | https://www.lcsc.com/product-detail/C2827654.html | 4.5144
4 | BZCN TSC016A04518A | Tactile Switches for console button | 5 | 0.0107 | 0.0535 | https://www.lcsc.com/product-detail/C2888493.html | 4.5679
5 | TI LM1117MP-3.3 | Voltage Regulators | 1 | 0.2975 | 0.2975 | https://www.lcsc.com/product-detail/C3750685.html | 4.8654
6 | XHXDZ 1207-P6.5MM | Buzzer | 1 | 0.0316 | 0.0316 | https://www.lcsc.com/product-detail/C49246964.html | 4.897
7 | 1N5817W | DIODE SCHOTTKY | 1 | 0.0197 | 0.0197 | https://www.lcsc.com/product-detail/C727113.html | 4.9167
8 | MMBT2222A | Bipolar Transistor | 1 | 0.0155 | 0.0155 | https://www.lcsc.com/product-detail/C7420351.html | 4.9322
9 | HS HS13L03W2C01 | 1.3" OLED | 1 | 5.3558 | 5.3558 | https://www.lcsc.com/product-detail/C7465997.html | 10.288
10 | muRata BLM21PG220SN1D | Ferrite Beads and Chips | 1 | 0.0308 | 0.0308 | https://www.lcsc.com/product-detail/C88993.html | 10.3188
11 | Resistor 1kΩ | R6 | 1 | 0.0011 | 0.0011 | https://www.lcsc.com/product-detail/C11702.html | 10.3199
12 | Capacitor 100nF | C2, C5 | 2 | 0.0016 | 0.0032 | https://www.lcsc.com/product-detail/C1525.html | 10.3231
13 | Capacitor 1uF | C3, C4 | 2 | 0.0098 | 0.0196 | https://www.lcsc.com/product-detail/C15849.html | 10.3427
14 | Korean Hroparts Elec TYPE-C-31-M-12 | USB C Input | 1 | 0.1725 | 0.1725 | https://www.lcsc.com/product-detail/C165948.html | 10.5152
15 | Capacitor 10uF | C1 | 1 | 0.25 | 0.25 | https://www.lcsc.com/product-detail/C19702.html | 10.7652
16 | B3U-1000P | ESP32 buttons | 3 | 0.1781 | 0.5343 | https://www.lcsc.com/product-detail/C231329.html | 11.2995
17 | Resistor 2.2kΩ | R7, R8 | 2 | 0.0008 | 0.0008 | https://www.lcsc.com/product-detail/C25879.html | 11.3003
18 | Resistor 5.1kΩ | R4, R5 | 2 | 0.0009 | 0.0018 | https://www.lcsc.com/product-detail/C25905.html | 11.3021
19 | Capacitor 22uF | C6, C7 | 2 | 0.0618 | 0.1236 | https://www.lcsc.com/product-detail/C45783.html | 11.4257
20 | R+O SMD1206-050-30 | Reset Fuse | 1 | 0.0599 | 0.0599 | https://www.lcsc.com/product-detail/C46641016.html | 11.4856
21 | ZHOURI 2.54-2*3 | Pin Header | 1 | 0.0562 | 0.0562 | https://www.lcsc.com/product-detail/C5116479.html | 11.5418
22 | Resistor 10kΩ | R1,R2,R3 | 3 | 0.0009 | 0.0027 | https://www.lcsc.com/product-detail/C60490.html | 11.5445
23 | 6x2mm Strong Magnet Neodymium | To make the enclosure easy to attach-dettach | 6 | 0.053 | 0.318 | https://tk.tokopedia.com/ZSxcDM12f/ | 11.8625
24 | M2X8 Screw | Screw PCB to enclosure | 4 | 0.05 | 0.2 | https://tk.tokopedia.com/ZSxcDKrx9/ | 12.0625
25 | M2 Nylon Nut | Locking the screw | 4 | 0.054 | 0.216 | https://tk.tokopedia.com/ZSxcP4PVw/ (https://tk.tokopedia.com/ZSxcUYBUF/) | 12.2785
26 | Engineering Fee | Engineering Fee | 1 | 24 | 24 | https://jlcpcb.com/ | 36.2785
27 | PCB Board | PCB Board | 1 | 1.6 | 1.6 | https://jlcpcb.com/ | 37.8785
28 | PCBA Price | If enabled PCBA option | 1 | 42.17 | 42.17 | https://jlcpcb.com/ | 80.0485

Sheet: POWERBANK
Number | Item | Description | Quantity | Unit Price ($) | Total Price ($) | URL | Running Total ($ with Tax)
1 | TPOWER TP4056 | Charging Module | 1 | 0.1194 | 0.1194 | https://www.lcsc.com/product-detail/C382139.html?globalKeyword=C382139&s_z=n_q_C382139 | 0.1194
2 | PUOLOP DW01A | Battery protection, prevents overcharging | 1 | 0.0428 | 0.0428 | https://www.lcsc.com/product-detail/C351410.html?globalKeyword=C351410&s_z=n_q_C351410 | 0.1622
3 | XI'AN Aerosemi Tech MT3608 | Boost Step-Up Regulator | 1 | 0.0786 | 0.0786 | https://www.lcsc.com/product-detail/C84817.html?globalKeyword=C84817&s_z=n_q_C84817 | 0.2408
4 | TECH PUBLIC FS8205A | LiPo Battery Protection |  | 0.0575 | 0.0575 | https://www.lcsc.com/product-detail/C2830320.html?globalKeyword=C2830320&s_z=n_q_C2830320 | 0.2983
5 | SHOU HAN TYPE-C 16PIN 2MD(073) | USB C Input and Output | 2 | 0.0742 | 0.1484 | https://www.lcsc.com/product-detail/C2765186.html?globalKeyword=C2765186&s_z=n_q_C2765186 | 0.4467
6 | Hubei KENTO Elec KT-0603R | Red Led | 1 | 0.007 | 0.007 | https://www.lcsc.com/product-detail/C2286.html?globalKeyword=C2286&s_z=n_q_C2286 | 0.4537
7 | Hubei KENTO Elec KT-0805G | Green Led | 1 | 0.0163 | 0.0163 | https://www.lcsc.com/product-detail/C2297.html?globalKeyword=C2297&s_z=n_q_C2297 | 0.47
8 | EVERLIGHT 19-213/BHC-ZL1M2RY/5T | Blue Led | 1 | 0.0381 | 0.0381 | https://www.lcsc.com/product-detail/C2987539.html?globalKeyword=C2987539&s_z=n_q_C2987539 | 0.5081
9 | cjiang FXL0420-4R7-M | Inductor | 1 | 0.2076 | 0.2076 | https://www.lcsc.com/product-detail/C167208.html?globalKeyword=C167208&s_z=n_q_C167208 | 0.7157
10 | JST S2B-PH-SM4-TB(LF)(SN) | JST Pin for Battery | 1 | 0.204 | 0.204 | https://www.lcsc.com/product-detail/C295747.html?globalKeyword=C295747&s_z=n_q_C295747 | 0.9197
11 | LiPo 104050 2000mAh 3.7V | Battery | 1 | 4.83 | 4.83 | https://tk.tokopedia.com/ZSxtYCQTL/ | 5.7497
12 | Resistor 5.1kΩ | R1,R2 | 2 | 0.0003 | 0.0006 | https://www.lcsc.com/product-detail/C23186.html | 5.7503
13 | Resistor 470Ω | R3,R4 | 2 | 0.0003 | 0.0006 | https://www.lcsc.com/product-detail/C23179.html | 5.7509
14 | Resistor 10kΩ | R5 | 1 | 0.0003 | 0.0003 | https://www.lcsc.com/product-detail/C25804.html | 5.7512
15 | Resistor 1.2kΩ | R6 | 1 | 0.0003 | 0.0003 | https://www.lcsc.com/product-detail/C114605.html | 5.7515
16 | Resistor 1kΩ | R7,R12 | 2 | 0.0003 | 0.0006 | https://www.lcsc.com/product-detail/C22548.html | 5.7521
17 | Resistor 110kΩ | R8 | 1 | 0.0002 | 0.0002 | https://www.lcsc.com/product-detail/C25805.html | 5.7523
18 | Resistor 15kΩ | R9 | 1 | 0.0003 | 0.0003 | https://www.lcsc.com/product-detail/C114661.html | 5.7526
19 | Resistor 56kΩ | R10,R11 | 2 | 0.0003 | 0.0006 | https://www.lcsc.com/product-detail/C23206.html | 5.7532
20 | Resistor 100Ω | R13 | 1 | 0.0003 | 0.0003 | https://www.lcsc.com/product-detail/C105588.html | 5.7535
21 | Capacitor 10uF | C1,C2 | 2 | 0.0019 | 0.0038 | https://www.lcsc.com/product-detail/C19702.html | 5.7573
22 | Capacitor 22uF | C3,C4 | 2 | 0.0027 | 0.0054 | https://www.lcsc.com/product-detail/C86295.html | 5.7627
23 | Capacitor 100nF | C6 | 1 | 0.0003 | 0.0003 | https://www.lcsc.com/product-detail/C160831.html | 5.763
24 | 3M Dual Lock Reclosable Fastener 24mm x 50cm Velcro acc (Usage 3mm x 3mm) | To make powerbank easy to attach-dettach | 6 | 0.001 | 0.006 | https://tk.tokopedia.com/ZSxcDnUcT/ | 5.769
25 | M2X8 Screw | Screw PCB to enclosure | 4 | 0.05 | 0.2 | https://tk.tokopedia.com/ZSxcDKrx9/ | 5.969
26 | M2 Nylon Nut | Locking the screw | 4 | 0.054 | 0.216 | https://tk.tokopedia.com/ZSxc5xuDv/ | 6.185
27 | PCB Board | PCB Board | 1 | 1 | 1 | https://jlcpcb.com/ | 7.185
28 | PCBA Price | If enabled PCBA option | 1 | 70.25 | 70.25 | https://jlcpcb.com/ | 77.435

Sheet: TOTAL
Item | Price | Running Total
Console | 80.0485 | 80.0485
Powerbank | 77.435 | 157.4835

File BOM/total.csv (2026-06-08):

Item | Price | Running Total
Console | 80.0485 | 80.0485
Powerbank | 77.435 | 157.4835

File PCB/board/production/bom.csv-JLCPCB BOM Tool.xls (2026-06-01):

JLCPCB BOM Tool - BOM Matching
BOM name：bom-JLCPCB Assembly Order.xlsx |  |  |  | Download Time：2026-05-30 23:47:17 |  |  |  | * Our matching results are updated in real-time, but stock and prices may change. If it's been over 24 hours, please re-match before placing your order.
PCB Assembled Qty：5 |  |  |  | Est. Total Price：68.6668 (Pre-order parts require a quotation for final pricing.)
Your BOM |  |  |  | Matched Parts |  |  |  |  |  |  | Order Information
Designator | Comment | Footprint | JLCPCB Part # | Matches | Part # | Manufacturer | Footprint | Description | Category | Warning | JLCPCB Part # | Product link | Source | Lib Type | MOQ | Availability | My Parts(JLCPCB Parts) | My Parts(Global sourcing & consigned parts) | Rec. Order Qty | Unit Price ($) | Total Price ($)
J1 | Pin 2x3 | PinHeader_2x03_P2.54mm_Vertical |  | Select by Customer | 2.54-2*3 | ZHOURI | PinHeader_2x03_P2.54mm_Vertical | -40℃~+105℃ 2 2.54mm 2.54mm 2.54mm 2.5A 2x3P 3mm 6P 6mm Brass Gold Pin Header Through Hole 插件,P=2.54mm Pin Headers ROHS | Pin Headers |  | C5116479 | https://jlcpcb.com/partdetail/ZHOURI-2_54_23/C5116479 | In-stock | Extended | 1 | 2427 | 0 | 0 | 5 | 0.0591 | 0.2955
SW1,SW2,SW3 | SW_SPST | SW_SPST_B3U-1000P |  | Unconfirmed | B3U-1000P | Omron Electronics | SW_SPST_B3U-1000P | -25℃~+70℃ 1.53N 1.6mm 12V 2.5mm 3mm 50mA Round Button SMD(SMT) Tab SPST Surface Mount,Vertical SMD,3x2.5mm Tactile Switches ROHS | Tactile Switches | 1.Multiple lines in the BOM have been matched to the same part. Please check if the matching is correct. ; | C231329 | https://jlcpcb.com/partdetail/OmronElectronics-B3U1000P/C231329 | In-stock | Extended | 1 | 165733 | 0 | 0 | 17 | 0.1768 | 3.0056
J2 | USB_C_Receptacle_USB2.0_16P | USB_C_Receptacle_HRO_TYPE-C-31-M-12 |  | Select by System | TYPE-C-31-M-12 | Korean Hroparts Elec | USB_C_Receptacle_HRO_TYPE-C-31-M-12 | -30℃~+80℃ 1 10,000 cycles 16P 20V 5A 7.35mm Female Surface Mount, Right Angle Type-C SMD USB Connectors ROHS | USB Connectors |  | C165948 | https://jlcpcb.com/partdetail/Korean_HropartsElec-TYPE_C_31_M12/C165948 | In-stock | Extended | 1 | 304779 | 0 | 0 | 5 | 0.1858 | 0.929
F1 | Polyfuse 1A | 1206 |  | Unconfirmed | SMD1206-050-30 | hongjiacheng | 1206 | -40℃~+85℃ 1.9mm 100ms 150mΩ 1A 1mm 3.6mm 30V 40A 500mA 600mW 750mΩ 1206 Resettable Fuses ROHS | Resettable Fuses | 1.The comment (SMD1206-050-30) of this part does not match the one (Polyfuse 1A) provided in your BOM. Please confirm; | C46641016 | https://jlcpcb.com/partdetail/hongjiacheng-SMD1206_05030/C46641016 | In-stock | Extended | 1 | 57968 | 0 | 0 | 9 | 0.0599 | 0.5391
C3,C4 | 1u | 0603 |  | Unconfirmed | CL10A105KB8NNNC | Samsung Electro-Mechanics | 0603 | 1uF 50V X5R ±10% 0603 Multilayer Ceramic Capacitors MLCC - SMD/SMT ROHS | Multilayer Ceramic Capacitors MLCC - SMD/SMT | 1.The comment (CL10A105KB8NNNC) of this part does not match the one (1u) provided in your BOM. Please confirm; | C15849 | https://jlcpcb.com/partdetail/16531-CL10A105KB8NNNC/C15849 | In-stock | Basic | 1 | 6081673 | 0 | 0 | 20 | 0.0098 | 0.196
U4 | USBLC6-2SC6 | SOT-23-6 |  | Select by System | USBLC6-2SC6 | TECH PUBLIC | SOT-23-6 | -55℃~+125℃ 0.35pF 12V 150W 2 5V 6A 6V 80nA ESD IEC 61000-4-2、IEC 61000-4-5、IEC 61000-4-4 Unidirectional SOT-23-6 ESD and Surge Protection (TVS/ESD) ROHS | ESD and Surge Protection (TVS/ESD) |  | C2827654 | https://jlcpcb.com/partdetail/TECHPUBLIC-USBLC62SC6/C2827654 | In-stock | Extended | 1 | 112314 | 0 | 0 | 9 | 0.041 | 0.369
FB1 | BLM21PG220 | 0805 |  | Select by System | BLM21PG220SN1D | Murata Electronics | 0805 | 1 22Ω@100MHz 6A 9mΩ ±25% 0805 Ferrite Beads ROHS | Ferrite Beads |  | C88993 | https://jlcpcb.com/partdetail/MurataElectronics-BLM21PG220SN1D/C88993 | In-stock | Extended | 1 | 62483 | 0 | 0 | 20 | 0.0305 | 0.61
D2,D3,D5 | ESD9B3.3 | D_SOD-923 |  | Select by System | TPESD9B3.3ST5G | TECH PUBLIC | D_SOD-923 | -55℃~+125℃ 1 10V 15pF 3.3V 4V 80W@8/20us 80nA 8A@8/20us ESD IEC 61000-4-2、IEC 61000-4-5 SOD-923(0402) ESD and Surge Protection (TVS/ESD) ROHS | ESD and Surge Protection (TVS/ESD) |  | C2682285 | https://jlcpcb.com/partdetail/TECHPUBLIC-TPESD9B33ST5G/C2682285 | In-stock | Extended | 1 | 36605 | 0 | 0 | 19 | 0.0396 | 0.7524
Q1 | MMBT2222A | SOT-23 |  | Select by System | MMBT2222A | hongjiacheng | SOT-23 | -55℃~+150℃ 1 NPN 100 100nA 1V 300MHz 300mW 40V 600mA 6V NPN SOT-23 Bipolar (BJT) ROHS | Bipolar (BJT) |  | C7420351 | https://jlcpcb.com/partdetail/hongjiacheng-MMBT2222A/C7420351 | In-stock | Extended | 1 | 164408 | 0 | 0 | 10 | 0.0154 | 0.154
OLED1 | HS13L03W2C01 | OLED-TH_L35.4-W33.5_HS13L03W2C01 |  | Select by System | HS13L03W2C01 | HS | OLED-TH_L35.4-W33.5_HS13L03W2C01 | -40℃~+70℃ 1.3 128x64 150cd/m2 29.42x14.7mm I2C Passive (PMOLED) SH1106 chip White - OLED Display ROHS | OLED Display |  | C7465997 | https://jlcpcb.com/partdetail/HS-HS13L03W2C01/C7465997 | In-stock | Extended | 1 | 606 | 0 | 0 | 5 | 5.3269 | 26.6345
U3 | LM1117MP-3.3 | SOT-223-3_TabPin2 |  | Select by System | LM1117MP-3.3 | Texas Instruments | SOT-223-3_TabPin2 | 0℃~+125℃@(Ta) 1 1.2V@(800mA) 15V 3.3V 5mA 75dB@(120Hz) 800mA 99uVrms Fixed Over Current Protection、Over Temperature Protection Positive SOT-223 Voltage Regulators - Linear, Low Drop Out (LDO) Regulators ROHS | Voltage Regulators - Linear, Low Drop Out (LDO) Regulators |  | C3750685 | https://jlcpcb.com/partdetail/TexasInstruments-LM1117MP_33/C3750685 | In-stock | Extended | 1 | 365 | 0 | 0 | 5 | 0.2979 | 1.4895
C2,C5 | 100n | 0402 |  | Unconfirmed | CL05B104KO5NNNC | Samsung Electro-Mechanics | 0402 | 100nF 16V X7R ±10% 0402 Multilayer Ceramic Capacitors MLCC - SMD/SMT ROHS | Multilayer Ceramic Capacitors MLCC - SMD/SMT | 1.The comment (CL05B104KO5NNNC) of this part does not match the one (100n) provided in your BOM. Please confirm; | C1525 | https://jlcpcb.com/partdetail/1877-CL05B104KO5NNNC/C1525 | In-stock | Basic | 1 | 13406579 | 0 | 0 | 20 | 0.0016 | 0.032
R6 | 1K | 0402 |  | Unconfirmed | 0402WGF1001TCE | UNI-ROYAL(Uniroyal Elec) | 0402 | -55℃~+155℃ 1kΩ 50V 62.5mW Thick Film Resistor ±1% ±100ppm/℃ 0402 Chip Resistor - Surface Mount ROHS | Chip Resistor - Surface Mount | 1.The comment (0402WGF1001TCE) of this part does not match the one (1K) provided in your BOM. Please confirm; | C11702 | https://jlcpcb.com/partdetail/12256-0402WGF1001TCE/C11702 | In-stock | Basic | 1 | 7323073 | 0 | 0 | 20 | 0.0011 | 0.022
R4,R5 | 5.1K | 0402 |  | Unconfirmed | 0402WGF5101TCE | UNI-ROYAL(Uniroyal Elec) | 0402 | -55℃~+155℃ 5.1kΩ 50V 62.5mW Thick Film Resistor ±1% ±100ppm/℃ 0402 Chip Resistor - Surface Mount ROHS | Chip Resistor - Surface Mount | 1.The comment (0402WGF5101TCE) of this part does not match the one (5.1K) provided in your BOM. Please confirm; | C25905 | https://jlcpcb.com/partdetail/26648-0402WGF5101TCE/C25905 | In-stock | Basic | 1 | 5357052 | 0 | 0 | 20 | 0.0009 | 0.018
D1 | 1N5817 | D_SOD-123 |  | Select by System | 1N5817W | TWGMC | D_SOD-123 | -55℃~+150℃ 1A 1mA 20V 25A 750mV@3A Independent SOD-123 Schottky Diodes ROHS | Schottky Diodes |  | C727113 | https://jlcpcb.com/partdetail/TWGMC-1N5817W/C727113 | In-stock | Extended | 1 | 54600 | 0 | 0 | 15 | 0.0205 | 0.3075
C1 | 10u | 0603 |  | Unconfirmed | CL10A106KP8NNNC | Samsung Electro-Mechanics | 0603 | 10V 10uF X5R ±10% 0603 Multilayer Ceramic Capacitors MLCC - SMD/SMT ROHS | Multilayer Ceramic Capacitors MLCC - SMD/SMT | 1.The comment (CL10A106KP8NNNC) of this part does not match the one (10u) provided in your BOM. Please confirm; | C19702 | https://jlcpcb.com/partdetail/20411-CL10A106KP8NNNC/C19702 | In-stock | Basic | 1 | 4479107 | 0 | 0 | 20 | 0.0124 | 0.248
C6,C7 | 22u | 0805 |  | Unconfirmed | CL21A226MAQNNNE | Samsung Electro-Mechanics | 0805 | 22uF 25V X5R ±20% 0805 Multilayer Ceramic Capacitors MLCC - SMD/SMT ROHS | Multilayer Ceramic Capacitors MLCC - SMD/SMT | 1.The comment (CL21A226MAQNNNE) of this part does not match the one (22u) provided in your BOM. Please confirm; | C45783 | https://jlcpcb.com/partdetail/46786-CL21A226MAQNNNE/C45783 | In-stock | Basic | 1 | 1813102 | 0 | 0 | 18 | 0.0618 | 1.1124
SW4,SW5,SW6,SW7,SW8 | SW_Push | SW-TH_4P-L4.5-W4.5-P3.00-LS4.8 |  | Select by System | TSC016A04518A | BZCN | SW-TH_4P-L4.5-W4.5-P3.00-LS4.8 | 1.8N 12V 4.5mm 4.5mm 4.5mm 50mA Black No Round Button SPST Through Hole Without Bracket 插件-4P,4.5x4.5mm Tactile Switches ROHS | Tactile Switches |  | C2888493 | https://jlcpcb.com/partdetail/BZCN-TSC016A04518A/C2888493 | In-stock | Extended | 1 | 4956 | 0 | 0 | 26 | 0.0107 | 0.2782
U1 | ESP32-C6-WROOM-1 | ESP32-C6-WROOM-1 |  | Select by System | ESP32-C6-WROOM-1-N8 | Espressif Systems | ESP32-C6-WROOM-1 | -40℃~+85℃ -99.2dBm 2.4GHz 20.5dBm 382mA 3V~3.6V 78mA ESP32-C6 On-board PCB Antenna UART、SPI、I2C、I2S、USB SMD,25.5x18mm WiFi Modules ROHS | WiFi Modules |  | C5366877 | https://jlcpcb.com/partdetail/6203223-ESP32_C6_WROOM_1N8/C5366877 | In-stock | Extended | 1 | 4131 | 0 | 0 | 5 | 4.3222 | 21.611
R7,R8 | 2K2 | 0402 |  | Unconfirmed | 0402WGF2201TCE | UNI-ROYAL(Uniroyal Elec) | 0402 | -55℃~+155℃ 2.2kΩ 50V 62.5mW Thick Film Resistor ±1% ±100ppm/℃ 0402 Chip Resistor - Surface Mount ROHS | Chip Resistor - Surface Mount | 1.The comment (0402WGF2201TCE) of this part does not match the one (2K2) provided in your BOM. Please confirm; | C25879 | https://jlcpcb.com/partdetail/26622-0402WGF2201TCE/C25879 | In-stock | Basic | 1 | 1353804 | 0 | 0 | 20 | 0.0008 | 0.016
BUZZER1 | 1207-P6.5MM | BUZ-TH_BD12.5-P6.50-D1.4 |  | Select by System | 1207-P6.5MM | XHXDZ | BUZ-TH_BD12.5-P6.50-D1.4 | -20℃~+70℃ 10mA 12mm 4kHz 5V 7mm 85dB Passive (Externally Driven) Piezoelectric 插件,D12.5xL7mm Buzzers ROHS | Buzzers |  | C49246964 | https://jlcpcb.com/partdetail/XHXDZ-1207_P65MM/C49246964 | In-stock | Extended | 1 | 1543 | 0 | 0 | 5 | 0.0315 | 0.1575
R1,R2,R3 | 10K | 0402 |  | Select by System | RC0402FR-0710KL | YAGEO | 0402 | -55℃~+155℃ 10kΩ 50V 62.5mW Thick Film Resistor ±1% ±100ppm/℃ 0402 Chip Resistor - Surface Mount ROHS | Chip Resistor - Surface Mount |  | C60490 | https://jlcpcb.com/partdetail/YAGEO-RC0402FR0710KL/C60490 | Pre-order | Extended | 10000 | 0 | 0 | 0 | 10000 | 0.0006 | 6
 |  |  |  |  |  |  |  |  | Tactile Switches | 1.Multiple lines in the BOM have been matched to the same part. Please check if the matching is correct. ; | C231329 | https://jlcpcb.com/partdetail/OmronElectronics-B3U1000P/C231329 |  | Extended | 0 | 165733 | 0 | 0 | 22 | 0.1768 | 3.8896

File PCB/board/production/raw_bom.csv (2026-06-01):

Designator | Footprint | Quantity | Value | LCSC Part #
BUZZER1 | BUZ-TH_BD12.5-P6.50-D1.4 | 1 | 1207-P6.5MM | C49246964
C1 | 0603 | 1 | 10u
C2, C5 | 0402 | 2 | 100n
C3, C4 | 0603 | 2 | 1u
C6, C7 | 0805 | 2 | 22u
D1 | D_SOD-123 | 1 | 1N5817
D2, D3, D5 | D_SOD-923 | 3 | ESD9B3.3
F1 | 1206 | 1 | Polyfuse 1A
FB1 | 0805 | 1 | BLM21PG220
H1, H2, H3, H4 | MountingHole_2.2mm_M2_DIN965_Pad | 4 | MountingHole
J1 | PinSocket_2x03_P2.54mm_Vertical | 1 | Pin 2x3
J2 | USB_C_Receptacle_HRO_TYPE-C-31-M-12 | 1 | USB_C_Receptacle_USB2.0_16P
OLED1 | OLED-TH_L35.4-W33.5_HS13L03W2C01 | 1 | HS13L03W2C01 | C7465997
Q1 | SOT-23 | 1 | MMBT2222A
R1, R2, R3 | 0402 | 3 | 10K
R4, R5 | 0402 | 2 | 5.1K
R6 | 0402 | 1 | 1K
R7, R8 | 0402 | 2 | 2K2
SW1, SW2, SW3 | SW_SPST_B3U-1000P | 3 | SW_SPST
SW4, SW5, SW6, SW7, SW8 | SW-TH_4P-L4.5-W4.5-P3.00-LS4.8 | 5 | SW_Push | C2888493
U1 | ESP32-C6-WROOM-1 | 1 | ESP32-C6-WROOM-1
U3 | SOT-223-3_TabPin2 | 1 | LM1117MP-3.3
U4 | SOT-23-6 | 1 | USBLC6-2SC6

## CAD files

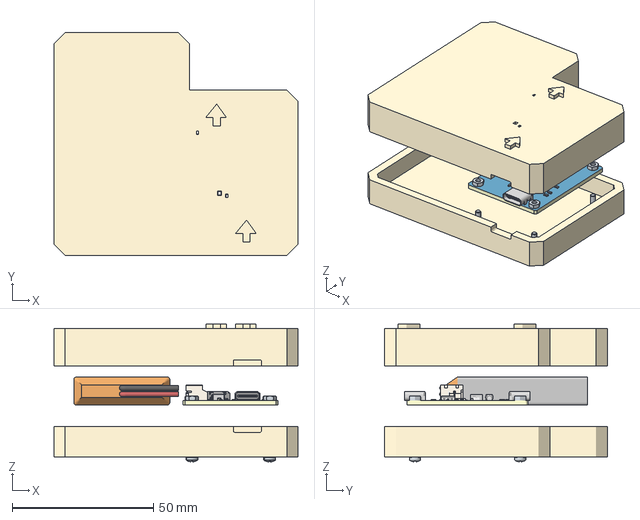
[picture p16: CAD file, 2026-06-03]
enclosure/powerbank/fullassemblyvisual.3mf
86.3 x 78.7 x 48.8 mm

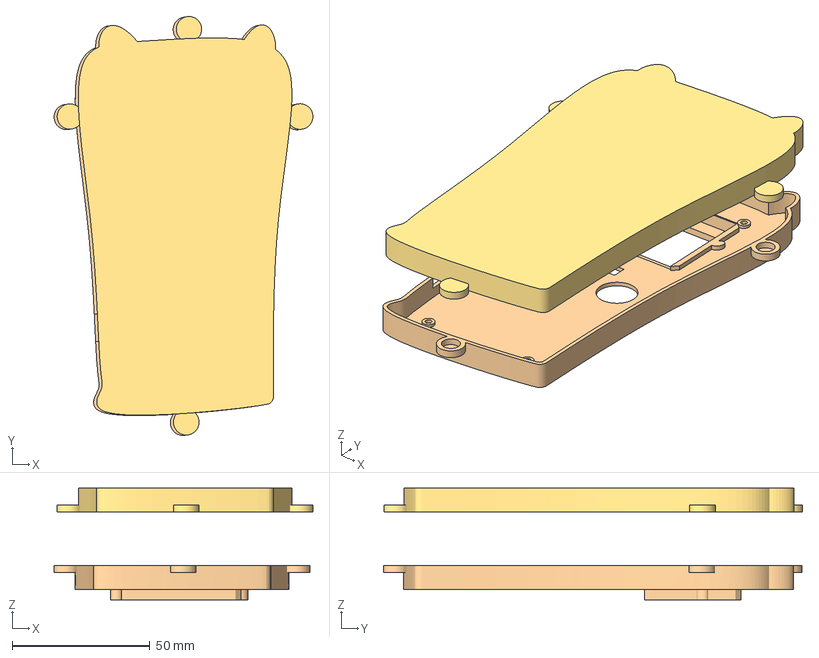
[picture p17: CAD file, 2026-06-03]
enclosure/console/enclosure_only.3mf
93.9 x 152.1 x 40.5 mm

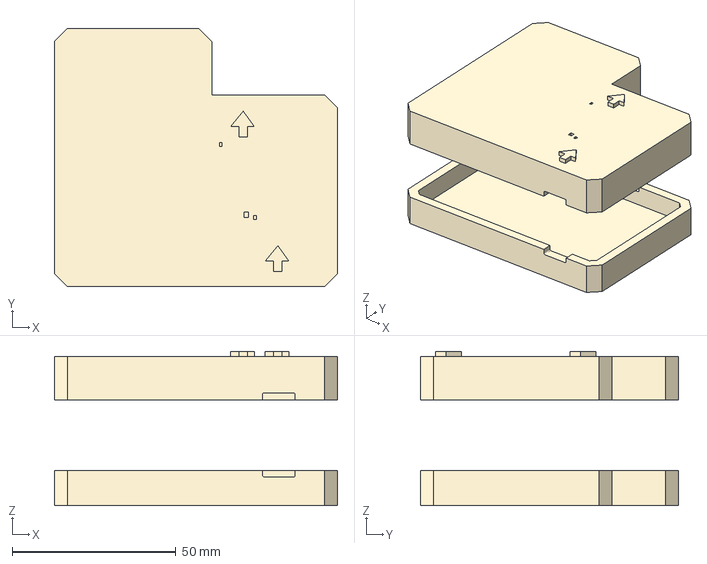
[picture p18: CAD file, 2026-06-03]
enclosure/powerbank/enclosure_only.3mf
86.3 x 78.7 x 47.0 mm

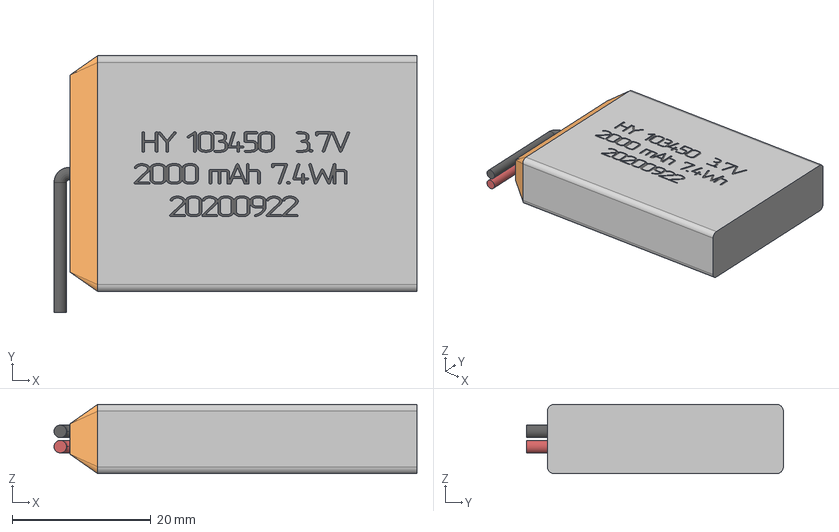
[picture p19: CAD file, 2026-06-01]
PCB/powerbank/STEP/Lp103450.stp
52.3 x 37.0 x 10.00 mm

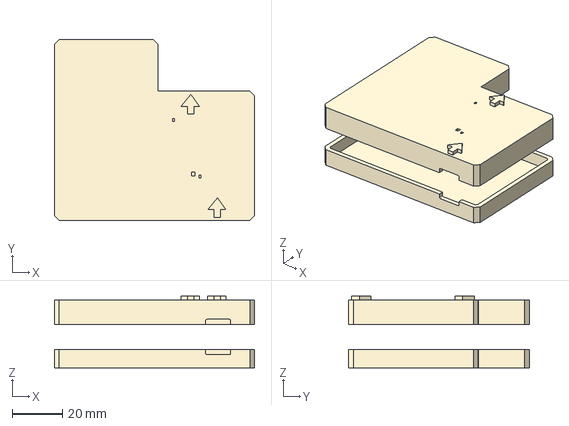
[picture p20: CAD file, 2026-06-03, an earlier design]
enclosure/powerbank/enclosure_assembly_old.3mf
79.3 x 71.7 x 28.4 mm

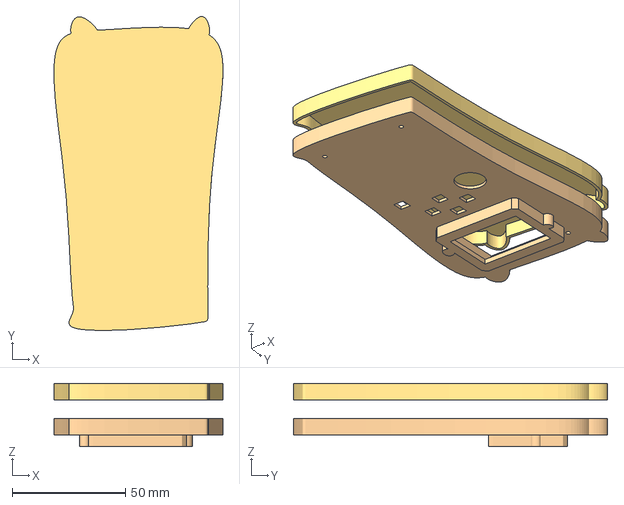
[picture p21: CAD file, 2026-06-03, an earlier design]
enclosure/console/enclosure_assembly_old.3mf
74.7 x 138.9 x 27.9 mm

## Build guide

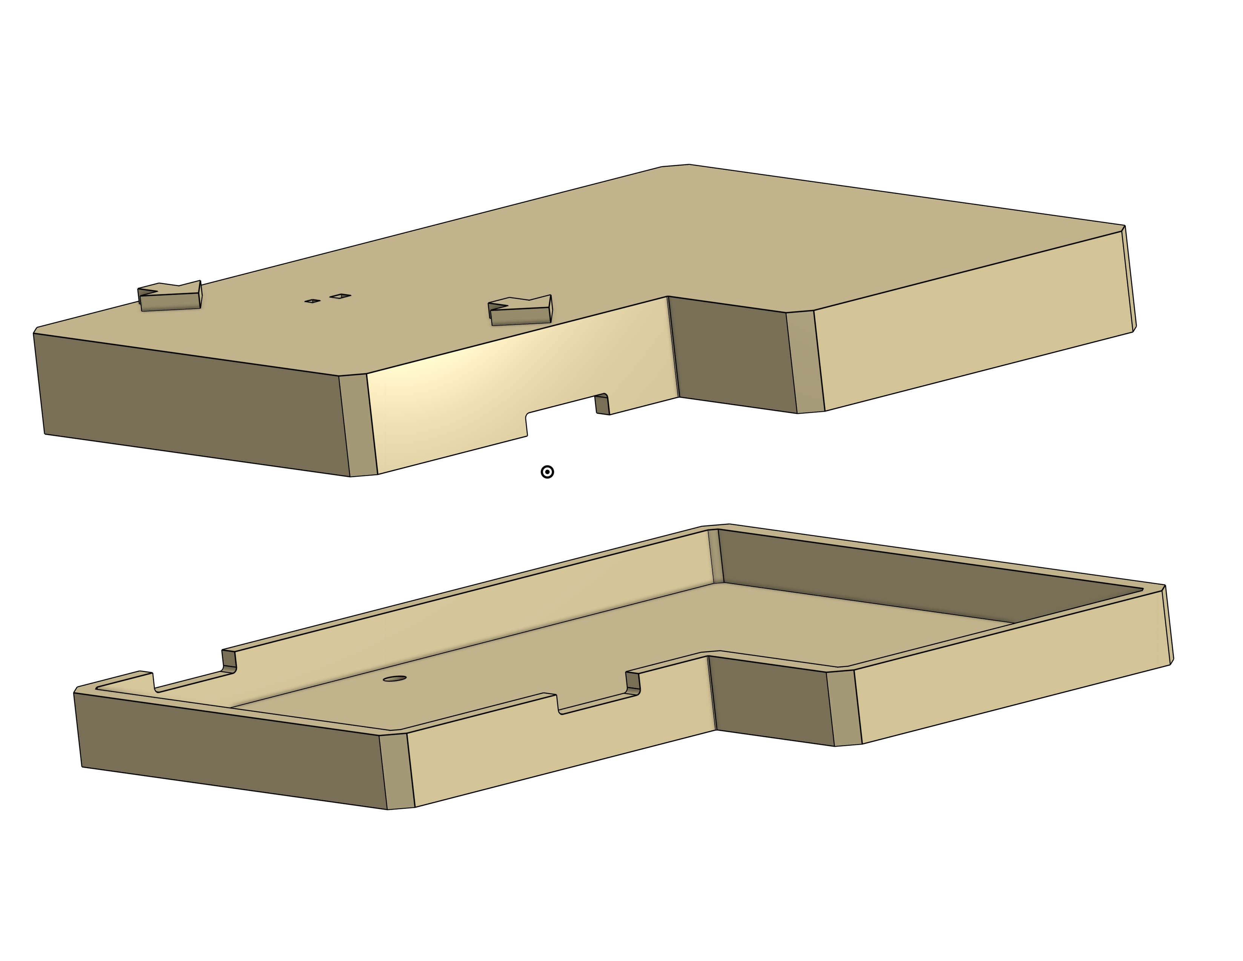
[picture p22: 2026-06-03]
enclosure/rawrenders/assembly_empty_powerbank.png

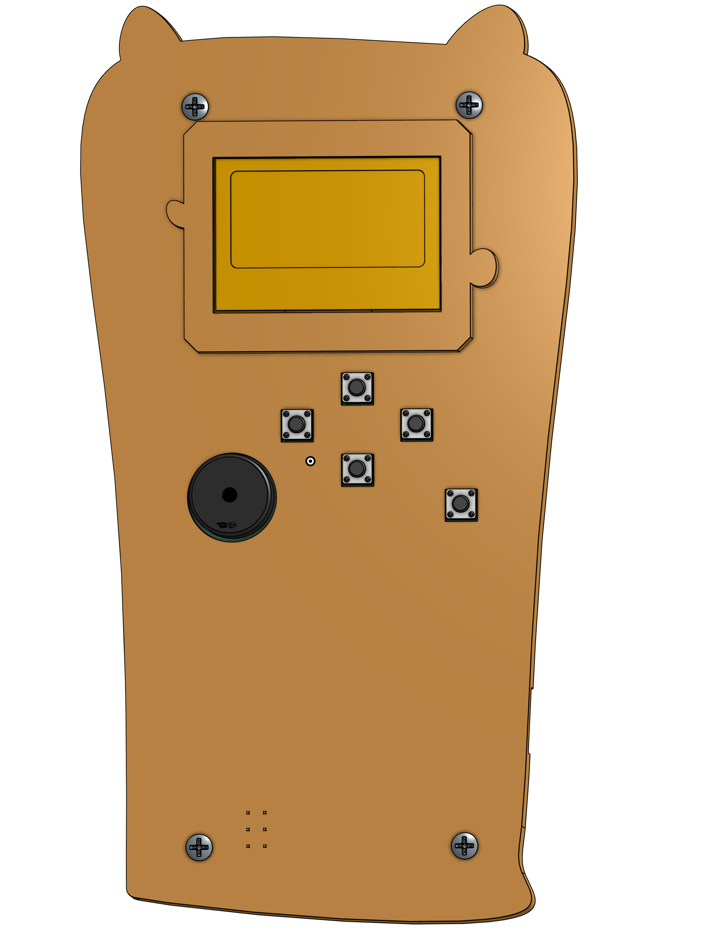
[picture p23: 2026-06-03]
enclosure/rawrenders/assembly_top.png

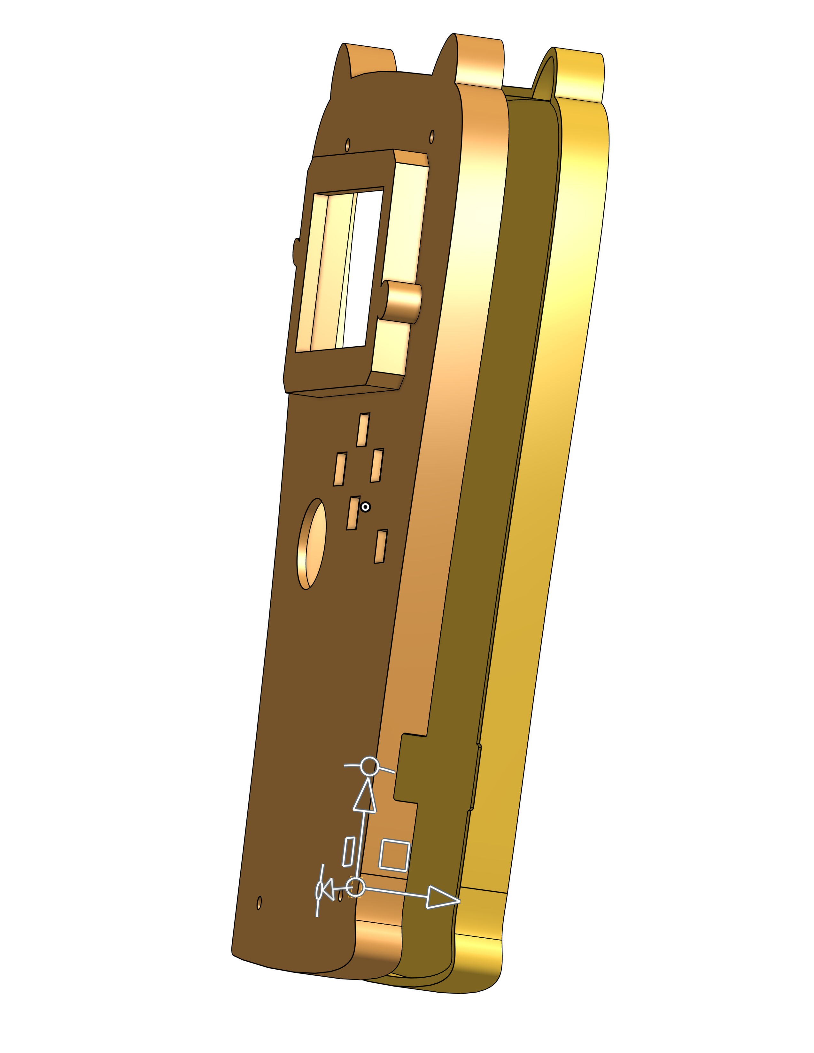
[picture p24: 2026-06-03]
enclosure/rawrenders/assembly_empty_console.png

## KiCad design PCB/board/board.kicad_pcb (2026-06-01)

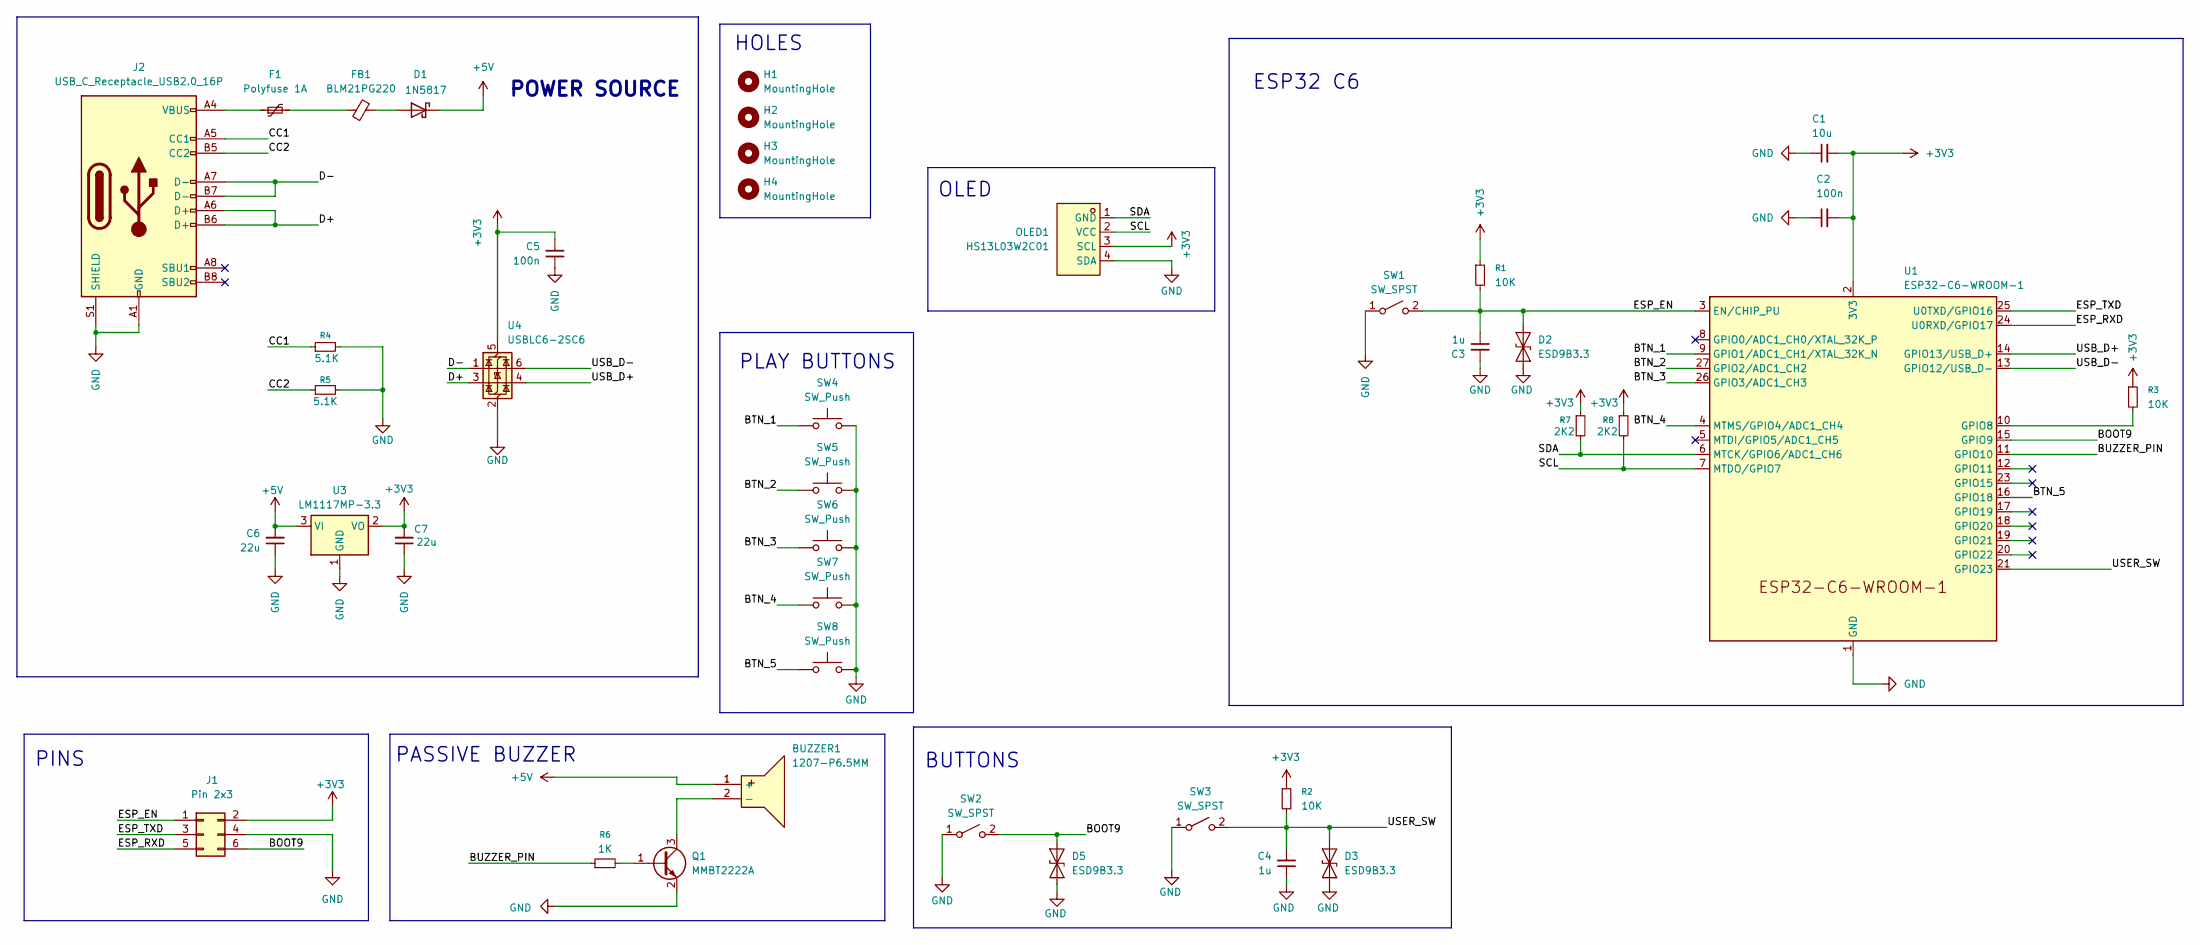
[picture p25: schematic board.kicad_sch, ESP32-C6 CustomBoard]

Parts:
BUZZER1: 1207-P6.5MM; BUZ-TH_BD12.5-P6.50-D1.4; MPN 1207-P6.5MM; LCSC Part C49246964
C1: 10u; C_0603_1608Metric
C2, C5: 100n; C_0402_1005Metric
C3, C4: 1u; C_0603_1608Metric
C6, C7: 22u; C_0805_2012Metric
D1: 1N5817; D_SOD-123
D2, D3, D5: ESD9B3.3; D_SOD-923
F1: Polyfuse 1A; Fuse_1206_3216Metric
FB1: BLM21PG220; L_0805_2012Metric
H1, H2, H3, H4: MountingHole; MountingHole_2.2mm_M2_DIN965_Pad
J1: Pin 2x3; PinSocket_2x03_P2.54mm_Vertical
J2: USB_C_Receptacle_USB2.0_16P; USB_C_Receptacle_HRO_TYPE-C-31-M-12
OLED1: HS13L03W2C01; OLED-TH_L35.4-W33.5_HS13L03W2C01; MPN HS13L03W2C01; LCSC Part C7465997
Q1: MMBT2222A; SOT-23
R1, R2, R3: 10K; R_0402_1005Metric
R4, R5: 5.1K; R_0402_1005Metric
R6: 1K; R_0402_1005Metric
R7, R8: 2K2; R_0402_1005Metric
SW1, SW2, SW3: SW_SPST; SW_SPST_B3U-1000P
SW4, SW5, SW6, SW7, SW8: SW_Push; SW-TH_4P-L4.5-W4.5-P3.00-LS4.8
U1: ESP32-C6-WROOM-1
U3: LM1117MP-3.3; SOT-223-3_TabPin2
U4: USBLC6-2SC6; SOT-23-6

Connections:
+3V3: C1.2, C2.2, C5.2, C7.2, J1.2, OLED1.3 (SCL), R1.1, R2.1, R3.1, R7.1, R8.1, U1.2 (3V3), U3.2 (VO), U4.5 (VBUS)
+5V: BUZZER1.1 (+), C6.2, D1.1 (K), U3.3 (VI)
/BOOT9: D5.2 (A2), J1.6, SW2.2 (B), U1.15 (GPIO9)
/BTN_1: SW4.2, U1.9 (GPIO1/ADC1_CH1/XTAL_32K_N)
/BTN_2: SW5.2, U1.27 (GPIO2/ADC1_CH2)
/BTN_3: SW6.2, U1.26 (GPIO3/ADC1_CH3)
/BTN_4: SW7.2, U1.4 (MTMS/GPIO4/ADC1_CH4)
/BTN_5: SW8.2, U1.16 (GPIO18)
/BUZZER_PIN: R6.1, U1.11 (GPIO10)
/CC1: J2.A5 (CC1), R4.1
/CC2: J2.B5 (CC2), R5.1
/D+: J2.A6 (D+), J2.B6 (D+), U4.3 (I/O2)
/D-: J2.A7 (D-), J2.B7 (D-), U4.1 (I/O1)
/ESP_EN: C3.1, D2.2 (A2), J1.1, R1.2, SW1.2 (B), U1.3 (EN/CHIP_PU)
/ESP_RXD: J1.5, U1.24 (U0RXD/GPIO17)
/ESP_TXD: J1.3, U1.25 (U0TXD/GPIO16)
/SCL: OLED1.2 (VCC), R8.2, U1.7 (MTDO/GPIO7)
/SDA: OLED1.1 (GND), R7.2, U1.6 (MTCK/GPIO6/ADC1_CH6)
/USB_D+: U1.14 (GPIO13/USB_D+), U4.4 (I/O2)
/USB_D-: U1.13 (GPIO12/USB_D-), U4.6 (I/O1)
/USER_SW: C4.2, D3.2 (A2), R2.2, SW3.2 (B), U1.21 (GPIO23)
GND: C1.1, C2.1, C3.2, C4.1, C5.1, C6.1, C7.1, D2.1 (A1), D3.1 (A1), D5.1 (A1), J1.4, J2.A1 (GND), J2.A12 (GND), J2.B1 (GND), J2.B12 (GND), J2.S1 (SHIELD), OLED1.4 (SDA), Q1.2 (E), R4.2, R5.2, SW1.1 (A), SW2.1 (A), SW3.1 (A), SW4.1, SW5.1, SW6.1, SW7.1, SW8.1, U1.1 (GND), U1.28 (GND), U1.29 (GND), U3.1 (GND), U4.2 (GND)
unnamed: BUZZER1.2 (-), Q1.3 (C)
unnamed: D1.2 (A), FB1.2
unnamed: F1.1, J2.A4 (VBUS), J2.A9 (VBUS), J2.B4 (VBUS), J2.B9 (VBUS)
unnamed: F1.2, FB1.1
unnamed: Q1.1 (B), R6.2
unnamed: R3.2, U1.10 (GPIO8)

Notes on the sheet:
PINS
OLED
PASSIVE BUZZER
PLAY BUTTONS
HOLES
ESP32 C6
BUTTONS
POWER SOURCE

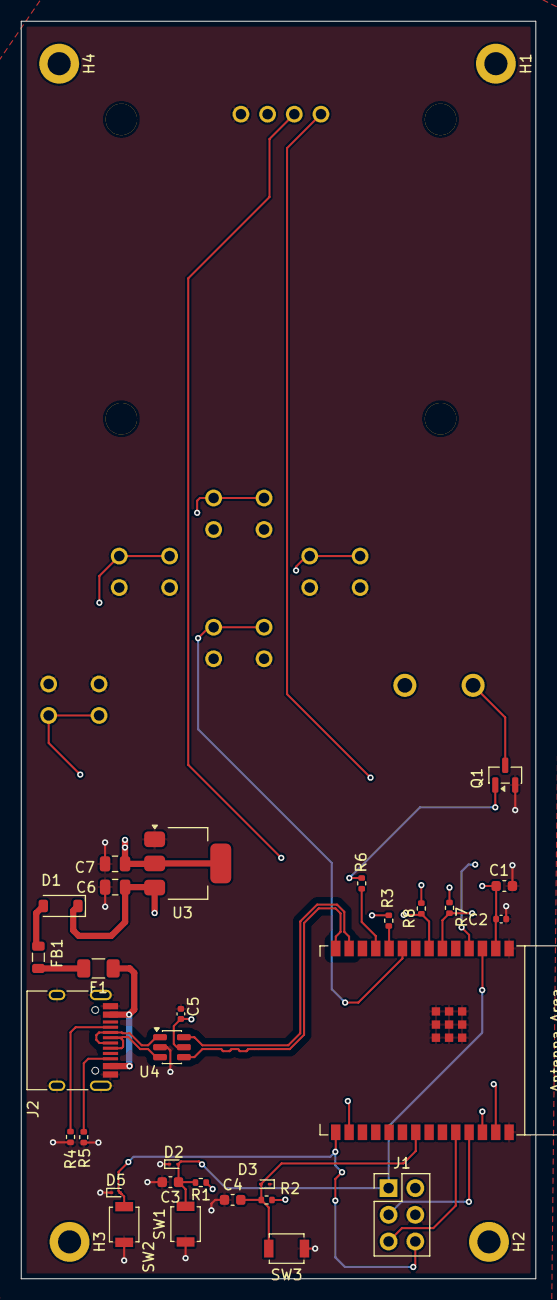
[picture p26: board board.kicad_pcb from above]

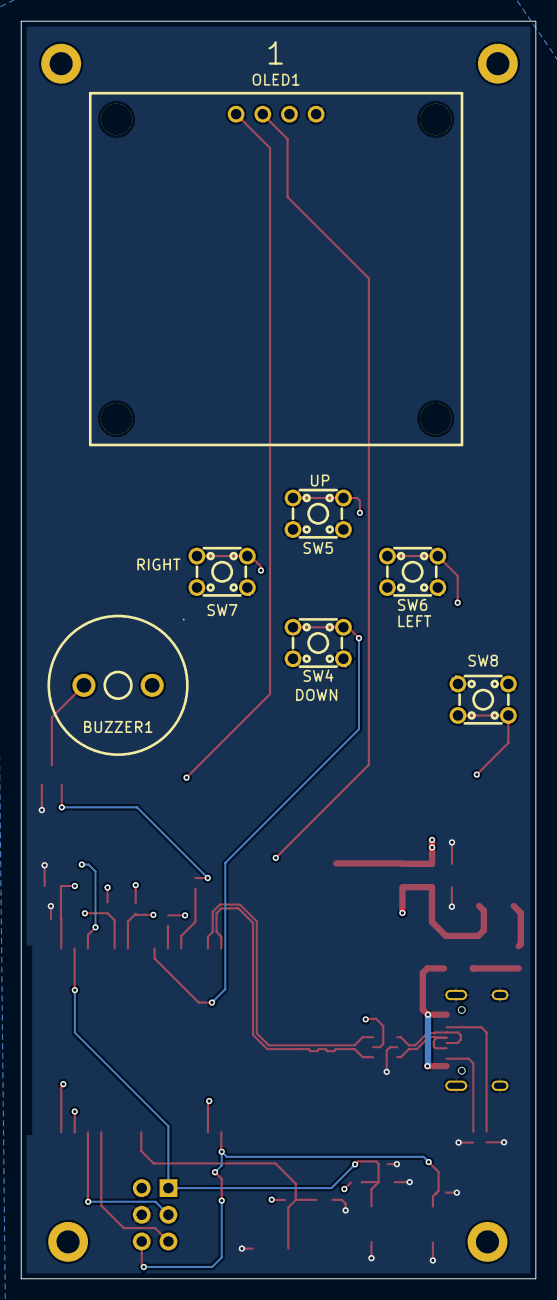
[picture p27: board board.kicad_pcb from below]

Board: 4 copper layers, 49.0 x 119.8 mm, 41 parts (7 on the bottom side), 28 nets.

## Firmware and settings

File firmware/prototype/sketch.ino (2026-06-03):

#include <Wire.h>
#include <Adafruit_GFX.h>
#include <Adafruit_SH110X.h>

#define DOWN_BTN  1
#define UP_BTN    2
#define RIGHT_BTN 3
#define LEFT_BTN  4
#define ACT_BTN   15

#define SCREEN_WIDTH 128
#define SCREEN_HEIGHT 64
#define OLED_RESET -1

Adafruit_SH1106G display(SCREEN_WIDTH, SCREEN_HEIGHT, &Wire, OLED_RESET);

String lastAction = "Ready!";
String lastBtn    = "";

struct BtnDef {
  int pin;
  const char* label;
  const char* action;
};

BtnDef buttons[] = {
  { DOWN_BTN,  "DOWN",  "Moving DOWN"  },
  { UP_BTN,    "UP",    "Moving UP"    },
  { RIGHT_BTN, "RIGHT", "Moving RIGHT" },
  { LEFT_BTN,  "LEFT",  "Moving LEFT"  },
  { ACT_BTN,   "ACT",   "ACTION!"      },
};

const int NUM_BUTTONS = sizeof(buttons) / sizeof(buttons[0]);

void showOLED(const char* btnName, const char* actionText){
  display.clearDisplay();

  display.setTextColor(SH110X_WHITE);
  display.setTextSize(1);
  display.setCursor(4, 3);
  display.print("ESP32-C6 Controller");

  display.setTextColor(SH110X_WHITE);
  display.setTextSize(2);
  int nameLen = strlen(btnName) * 12;
  display.setCursor((SCREEN_WIDTH - nameLen) / 2, 20);
  display.print(btnName);

  display.setTextSize(1);
  int actionLen = strlen(actionText) * 6;
  display.setCursor((SCREEN_WIDTH - actionLen) / 2, 47);
  display.print(actionText);

  display.display(); 
}

void setup(){
  Serial.begin(115200);

  for(int i = 0; i < NUM_BUTTONS; i++){
    pinMode(buttons[i].pin, INPUT_PULLUP);
  }

  Wire.begin(6,7);
  if(!display.begin(0x3C, true)){
    Serial.print("Init failed");
  }

  display.clearDisplay();
  display.display();
}

void loop() {
  for (int i = 0; i < NUM_BUTTONS; i++) {
    if (digitalRead(buttons[i].pin) == LOW) {
      if (lastBtn != buttons[i].label) {          
        lastBtn    = buttons[i].label;
        lastAction = buttons[i].action;
        Serial.println(lastAction);
        showOLED(buttons[i].label, buttons[i].action);
      }
      delay(10);
      return;                                    
    }
  }
  lastBtn = ""; 
  delay(10);
}

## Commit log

2026-06-03 Adding Firmware, BOM modification and Enclosure modification. Added README and Zine
    [REAL_BOM.csv, REAL_BOM.xlsx, all.xlsx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]
2026-06-03 Added BOM links
2026-06-03 Added combined BOM
    [BOM.csv]
2026-06-03 Added combined BOM and renamed folder
    [BOM.csv, all.xlsx, console.csv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]
2026-06-03 Added schematic and PCB screenshots
2026-06-08 Added engineering fee, board price, and PCBA service to the BOM.. Updated BOM and README (now Readme also have running total)
    [BOM.csv, all.xlsx, console.csv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]
